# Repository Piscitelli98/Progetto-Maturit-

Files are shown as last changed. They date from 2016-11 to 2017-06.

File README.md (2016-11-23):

# Progetto Maturità
Cassaforte
Titolo: Cassaforte con Arduino.
Gruppo: Perego Daniele, Piscitelli Federico, Leggio Giuseppe.
Spiegazione: Un modello di cassaforte costruita con Arduino, integrando un sensore di impronte digitali, un tastierino numerico, un display e una shield per la comunicazione wireles.
La cassaforte permetterà di avere accesso a un database in cui sono registrati tutti gli accessi.
Saremo in grado di rilevare anche la persona che ha eseguito l'accesso poichè si avranno a disposizione degli identificativi grazie all'impronta digitale.
L'accesso a questo database sarà effettuato tramite applicazione android.

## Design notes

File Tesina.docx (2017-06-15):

# Cassaforte 2.0

Di

Piscitelli Federico

Leggio Giuseppe

Perego Daniele

Rosselli Mattia

# Introduzione

L’ idea

L’ idea di creare una cassaforte smart è nata dall’ esigenza di creare un prodotto innovativo non ancora presente sul mercato. Un altro aspetto che ci ha spinto alla realizzazione di questo progetto è la possibilità di estendere il meccanismo di sicurezza ad altri ambiti, come ad esempio in quello della domotica.

Quali funzioni offre

Oltre ad essere una normale cassaforte, il nostro prototipo offre diverse funzionalità che rappresentano sicuramente delle innovazioni nel campo della sicurezza. Prime fra tutte:

- Sensore di impronte digitali
- Applicazione android
- Comunicazione bluetooth
- Registrazione con successiva consultazione tramite app

# Obiettivi

La Cassaforte 2.0 si pone come obiettivo quello di creare un progetto sicuro, affidabile e intuitivo, con l’aggiunta di alcune funzioni “smart”.

INNOVAZIONE

Questo progetto pone come primo obiettivo quello di trasformare un oggetto millenario in qualcosa di moderno, al passo con i tempi.

Il primo passo per la modernizzazione della cassaforte avviene tramite l’aggiunta di un sensore per il rilevamento dell’impronta digitale, diventato ormai un must della sicurezza.

Per rendere ancora più all’avanguardia questo progetto ci si è chiesto: “Quale oggetto oggi rappresenta l’innovazione?” Subito è saltato all’occhio lo smartphone che al giorno d’ oggi è parte integrante della nostra vita.

Il modo migliore per combinare questi due mondi è stato quello di sviluppare un’applicazione dedicata alla gestione della cassaforte.

Nonostante il progetto preveda l’utilizzo dello smartphone per alcune funzioni, la cassaforte può svolgere la sua normale funzione di custodia anche senza l’obbligo di utilizzo dell’applicazione, rendendo accessibile a tutti , grandi e piccoli, le sue funzioni, ampliando così il range di persone raggiungibili nel mercato.

SICUREZZA

Uno degli obiettivi fondamentali della Cassaforte 2.0 è quello di garantire una sicurezza costante ed efficiente. Per fare ciò il prototipo propone due livelli di sicurezza:

1. Tastierino numerico
2. Sensore d’ impronte digitali

Proprio grazie a questo doppio livello di sicurezza, anche scoperto il codice di apertura, risulta impossibile l’apertura in maniera fraudolenta della cassaforte.

# Strumenti

La Cassaforte 2.0 utilizza un Arduino che permette una completa adattabilità data dalla possibilità di poter compilare il codice in base alle necessità del cliente, dando la possibilità di aggiungere o modificare la varia componentistica.

STRUMENTI UTILIZZATI

- Arduino mega (modello) e componentistica reperibile in rete. Si è optato per il mega data la sua migliore capacità di calcolo e la possibilità di inserimento di più pin.

- Cassaforte in legno per simulare un reale caso d’uso.

- Android studio e Arduino come ambienti di sviluppo per la programmazione.

- Librerie reperibili in internet ed adattate al caso d’uso specifico per permettere la comunicazione e la realizzazione di servizi mirati.

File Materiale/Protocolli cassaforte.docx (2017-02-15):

# Protocolli cassaforte

# Registrazione del primo utente

Client

Android

Server

Arduino

connessione

ok

registra;”user”;”psw”;”cod”

ok

Close

# Login

Client

Android

Server

Arduino

connessione

ok

Log;”user”;”psw”

ok

Close

# Apertura cassaforte da applicazione

close

ok

apri;”cod”;”user”

ok

connessione

Client

Android

Server

Arduino

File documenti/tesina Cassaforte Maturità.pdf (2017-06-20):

## 5ªA Informatica e Telecomunicazioni Esame di Stato A.S. 2016/2017

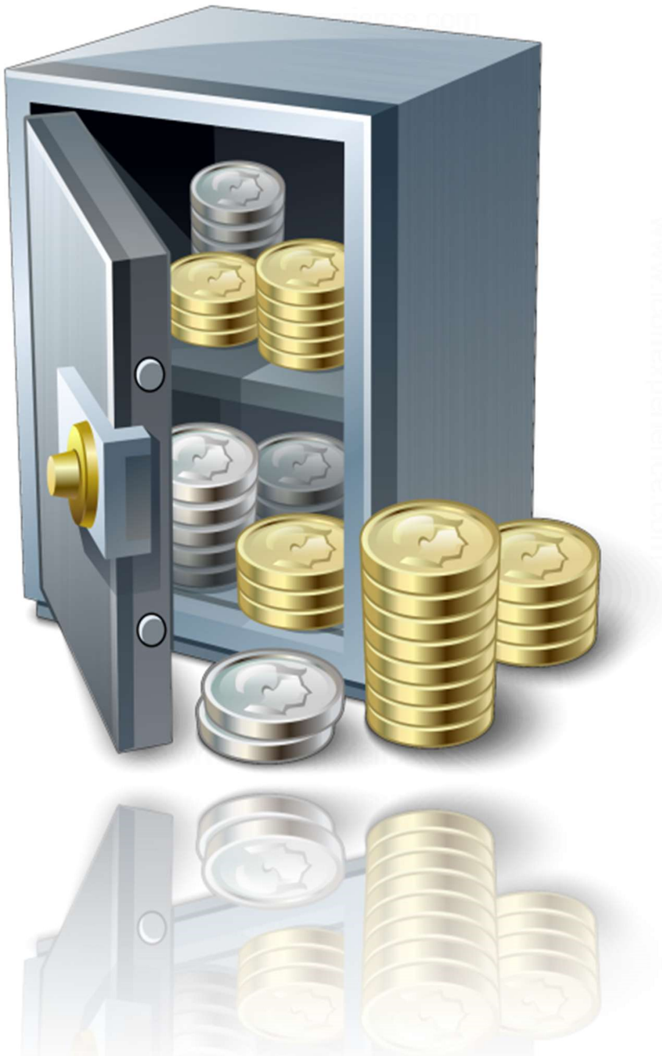
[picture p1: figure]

# Cassaforte

2.0

Di

Piscitelli Federico
Leggio Giuseppe
Perego Daniele
Rosselli Mattia

1

SOMMARIO

2

INTRODUZIONE

L’ IDEA
L’ idea di creare una cassaforte smart è nata dall’ esigenza di creare un prodotto innovativo non ancora presente sul mercato. Un altro aspetto che ci ha spinto alla realizzazione di questo progetto è la possibilità di estendere il meccanismo di sicurezza ad altri ambiti, come ad esempio in quello della domotica.

QUALI FUNZIONI OFFRE
Oltre ad essere una normale cassaforte, il nostro prototipo offre diverse funzionalità che rappresentano sicuramente un approccio innovativo nel campo della sicurezza. Prime fra tutte:
- Applicazione Android
- Comunicazione Bluetooth
- Registrazione con successiva consultazione tramite app
- Sensore di riconoscimento biometrico

3

OBIETTIVI

La Cassaforte 2.0 si pone come obiettivo quello di creare un progetto sicuro, affidabile e intuitivo, con l’aggiunta di alcune funzioni “smart”.

INNOVAZIONE
Questo progetto pone come primo obiettivo quello di trasformare un oggetto millenario in qualcosa di moderno, al passo con i tempi.
Il primo passo per la modernizzazione della cassaforte avviene tramite l’aggiunta di un sensore per il rilevamento dell’impronta digitale, diventato ormai un must della sicurezza.
Per rendere ancora più all’avanguardia questo progetto ci si è chiesto: “Quale oggetto oggi rappresenta l’innovazione?”
Subito è saltato all’occhio lo smartphone che al giorno d’ oggi è parte integrante della nostra vita.
Il modo migliore per combinare questi due mondi è stato quello di sviluppare un’applicazione dedicata alla gestione della cassaforte. Nonostante il progetto preveda l’utilizzo dello smartphone per alcune funzioni, la cassaforte può svolgere la sua normale funzione di custodia anche senza l’obbligo di utilizzo dell’applicazione, rendendo accessibile a tutti , grandi e piccoli, le sue funzioni, ampliando così il range di persone raggiungibili nel mercato.

SICUREZZA

Uno degli obiettivi fondamentali della Cassaforte 2.0 è quello di garantire una sicurezza costante ed efficiente.
Per fare ciò il prototipo propone una doppia chiave in base al caso d’uso:

### 1. Tastierino numerico 2. Sensore d’ impronte digitali

Proprio grazie a questo doppio livello di sicurezza, anche scoperto il codice di accesso, risulato quasi impossibile l’apertura in maniera fraudolenta della cassaforte.

4

STRUMENTI

La Cassaforte 2.0 utilizza un Arduino che permette una completa adattabilità, data dalla possibilità di poter compilare il codice in base alle necessità del cliente, dando la possibilità di aggiungere o modificare la varia componentistica.

STRUMENTI UTILIZZATI

- Arduino Mega
- Modulo RTC (Real Time Clock, utile per tenere ora e giorno)
- Modulo Bluetooth HC-06
- Modulo per l’espansione della memoria
- Sensore d’impronte digitale
- Schermo LCD
- Motorino Step to Step
- Cassaforte in legno per simulare un reale caso d’uso.
- Android Studio e Arduino IDE come ambienti di sviluppo per la programmazione.
- Librerie fornite dai vari costruttori dei componenti

Durante la fase di progettazione si è deciso di utilizzare un Arduino Mega, a dispetto di un Arduino UNO, per la posssibilità di scalabilità che offriva il primo, data la quantità di pin disponibili.

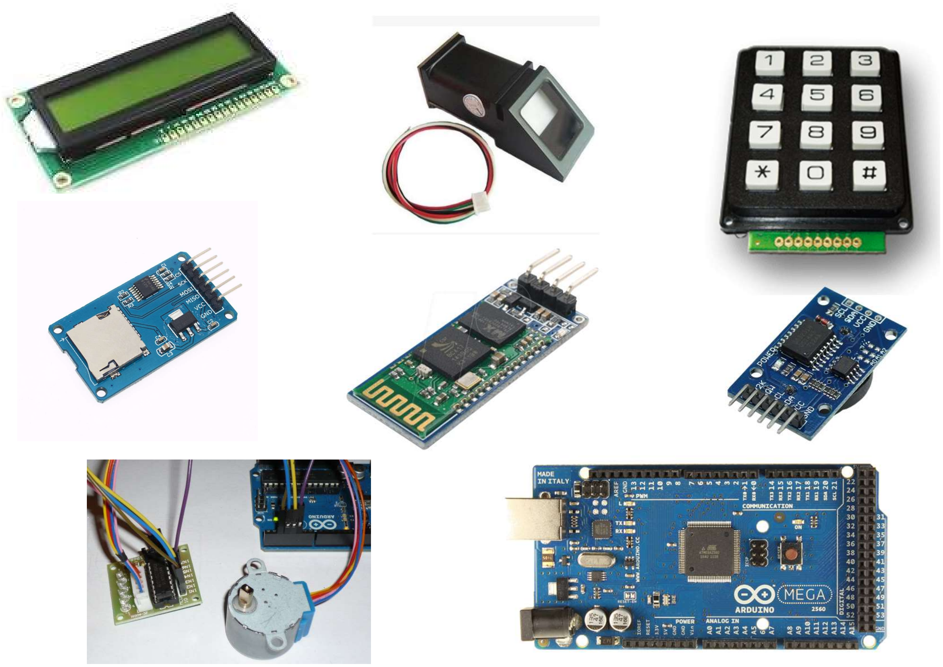
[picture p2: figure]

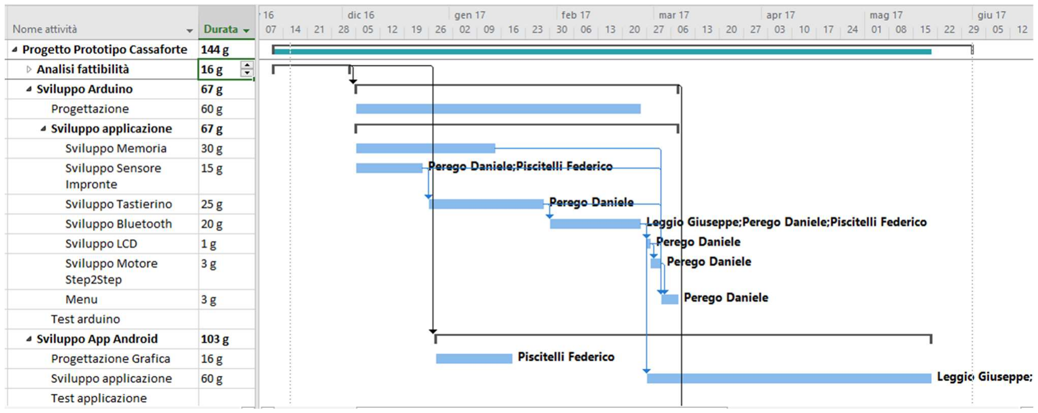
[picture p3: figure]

5

METODOLOGIA E SVILUPPO
Essendoci due ambienti di sviluppo differenti si è optato per la divisione del team in due rami.

Il primo gruppo, composto da Leggio e Piscitelli, si è impegnato nella programmazione e nello sviluppo dell’applicazione Android.
Il secondo gruppo, composto da Perego e Rosselli, ha avuto come incarico il montaggio dei vari componenti hardware e la programmazione delle sue funzionalità.

TEMPISTICHE
Per organizzare al meglio i tempi e le risorse abbiamo utillizzato Microsoft Project, con il qule siamo riusciti a stilare una WBS che è stata rispettata da tutti i componenti del gruppo.

6

ANDROID
Lo sviluppo dell’applicazione Android si è divisa in tre fasi:
- Progettazione e realizzazione della grafica;
- Gestione file di log e ultimi accessi scaricati;
- Implementazione della comunicazione Bluetooth per le varie funzionalità.
Durante la prima fase, si è realizzato un “bozzetto” in Android Studio di come sarebbe dovuta essere l’applicazione. Si è passati poi alla creazione dei colori per i bottoni e per lo sfondo. Successivamente sono state implementate tutte le animazioni nelle varie activity.
La parte più impegnativa a livello di design è arrivata quando si è dovuto implementare il Fragment, un elemento introdotto con Android 3, per la creazione di interfacce grafiche. È una sorta di sub activity. Infatti il suo funzionamento è legato ad un’activity principale.
La struttura di questo tipo di programmazione consiste nel creare diversi layout per ogni fragment (vista) che viene implementata, essi poi vanno collegati a una corrispondete classe, proprio come se fosse un’activity, con la differenza che poi queste diverse “viste” sono gestite da un’activity principale.
Questo ne rende più difficile la gestione in quanto tutti i metodi per richiamare dei componenti grafici dal file xml sono differenti. Ad esempio per richiamare un bottone in un’activity semplice si scrive questa linea di codice:

Button button = (Button)findViewById(R.id.button0);
Mentre in un Fragment:
View rootView = inflater.inflate(R.layout.fragment_layout, container, false);
Button button =
(Button)rootView.findViewById(R.id.button0);

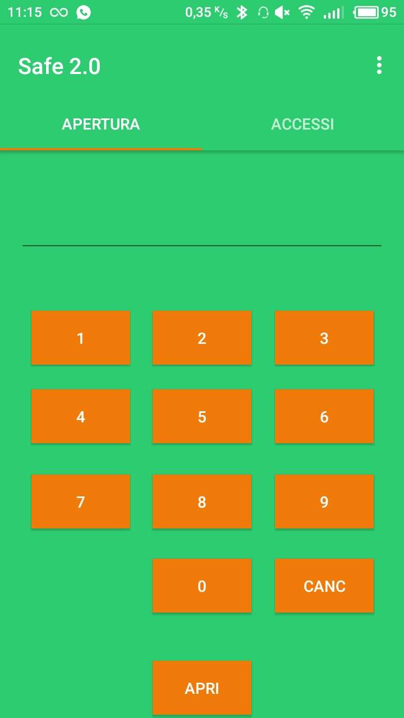
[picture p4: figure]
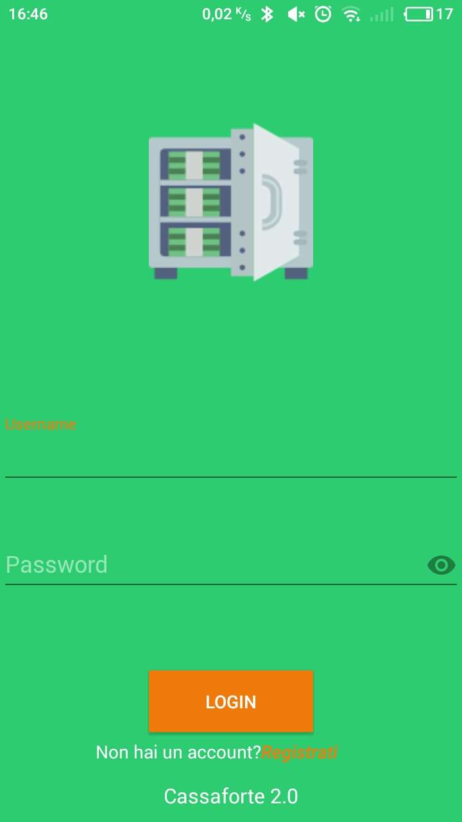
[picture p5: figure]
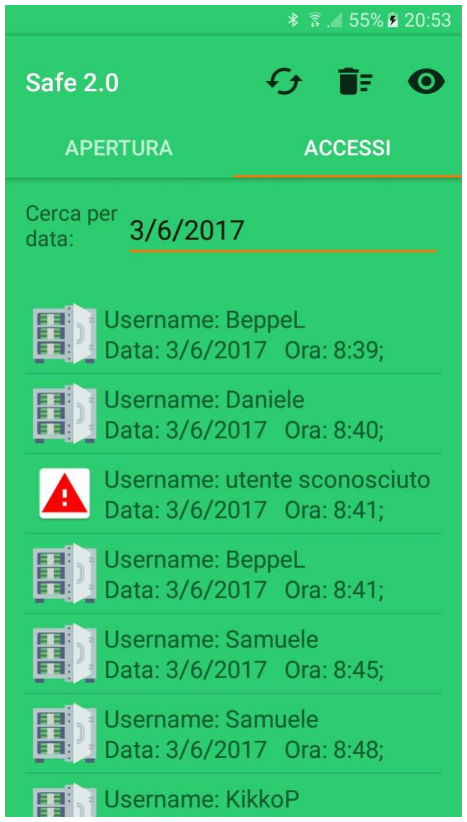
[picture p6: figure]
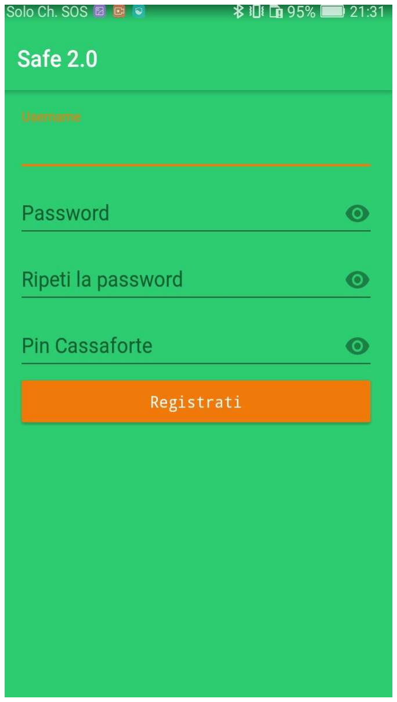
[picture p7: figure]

7

La fase seguente è stata l’implementazione della gestione dei file. L’implementazione si è resa necessaria perché si voleva garantire la possibilità di utilizzare l’applicazione in parte anche quando l’applicazione non è connessa alla Cassaforte.
I file di log che vengono registrati sono due:
- Il primo che memorizza i dati di accesso una volta che è stato eseguito con successo il login tramite connessione.
- Il secondo che memorizza gli ultimi accessi scaricati.

private Boolean leggiFileLog(String datiLogin)
String line = "";//Riga letta BufferedReader br;
boolean trovato = false;
try {
FileInputStream fin = openFileInput(filename);
int c;//Indice linea del file corrente
while ((c = fin.read()) != -1) {//legge un carattere alla volta if ((char) c != '%') //carattere che delimita login salvata line += Character.toString((char) c);//forma login
else {//una volta trovato lo confronta con i
if (line.equals(datiLogin)) {//dati inseriti dall’utente trovato = true;
break;
}
line = "";
}
}
} catch (Exception e) {}
return trovato;//ritorna true o false in base se ha trovato o meno la corrispondenza con i dati inseriti dall'utente
}

L’ultima fase, quella più lunga e in cui sono emerse notevoli difficoltà, è stata quella in cui è stata implementata la comunicazione Bluetooth. Per comunicare con la Cassaforte utilizza tre elementi:
- La classe “BluetoothComIno”, creata da Leggio. Il principio di questa classe è quello di istanziare una socket, che ha come IP il MAC del modulo HC-06, e come porta richiama questo metodo,
BluetoothDevice.createRfcommSocketToServiceRecord(uuid), il quale permette di aprire una connessione p2p.
- Un thread per la ricezione dei dati. Esso viene utilizzato poiché, oltre a un motivo di strettamente computazionale, nel sistema Android, questo tipo di operazioni non possono essere gestite dal main-thread, bisogna utilizzare dei worker-thread.
- Un handler. Poiché i dati devono poi essere elaborati dal main thread, diventa necessario l’utilizzo di questo oggetto, perché permette la comunicazione tra main-thread e worker-thread.
In sintesi quindi, questo strumento fa da intermediario tra worker thread e main thread utilizzando un oggetto di tipo Message, il

8

quale viene aggiornato dal worker thread e passato tramite bundle al main thread in cui poi viene elaborato.

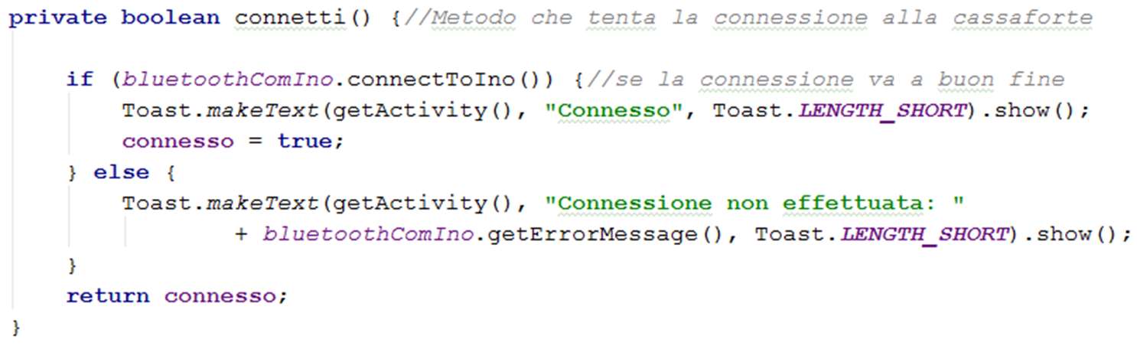
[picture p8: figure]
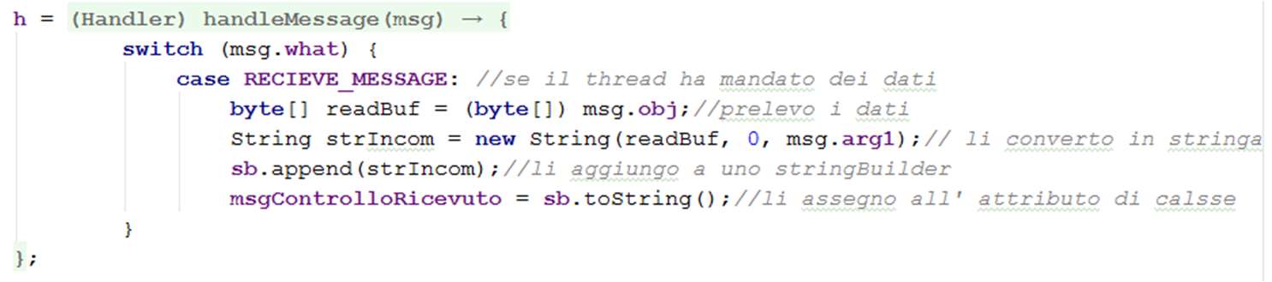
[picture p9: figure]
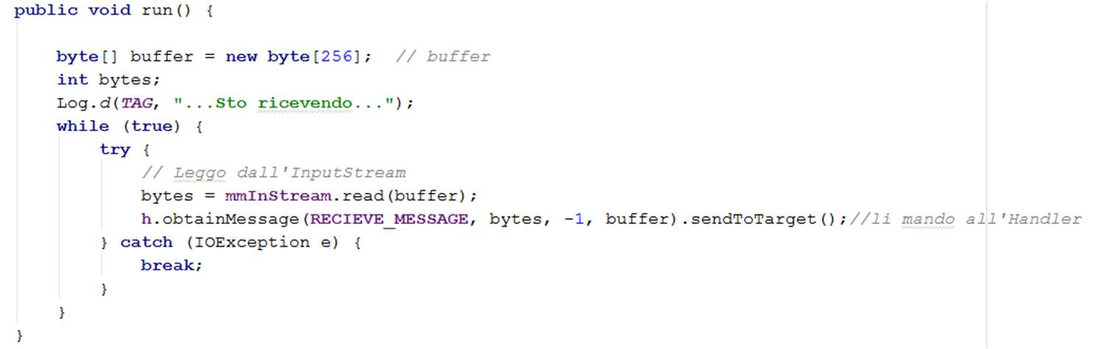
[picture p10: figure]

Durante la programmazione della comunicazione Bluetooth sono stati riscontrati diversi problemi, soprattutto riguardanti la ricezione. Molte volte infatti venivano persi o duplicati caratteri.
Il problema derivava principalmente da due fattori:
- l’Arduino venivano utilizzato spesso in modalità “Debug” e ciò creava degli scompensi nella comunicazione.
- Un’alimentazione non sufficiente. Questo è stato riscontrato nei casi in cui è stato usato un net-book come alimentatore, dal quale esce corrente in modo poco stabile. Se l’Arduino è collegato invece ad una fonte di alimentazione esterna, che non sia una porta USB del pc, questo problema non persiste.
Altri problemi sono emersi nuovamente per via dell’utilizzo del via del menu Fragment, per via del suo ciclo di vita differente rispetto alla normale activity.
Essendo collegati entrambi alla stessa activity, essi vengono creati allo

9

stesso momento. Di conseguenza è stato necessario anche sincronizzare quale dei due si doveva connettere per primo, e le varie fasi di disconnessione e riconnessione.

ARDUINO
Anche lo sviluppo di Arduino e dei componenti è stato diviso in due momenti:
- Programmazione e test dei singoli componenti
- Assemblaggio e test complessivo
Per la parte fisica abbiamo subito riscontrato delle problematiche, siccome abbiamo dovuto attendere più di un mese dall’acquisto dei componenti affinché questi arrivassero. Una volta arrivata la componentistica, il team hardware si è diviso in due e ha cominciato a testare e a programmare uno ad uno ogni modulo.
I primi problemi sono stati riscontrati con il tastierino numerico che non corrispondeva allo schema elettrico fornitoci dal venditore. Quindi il gruppo hardware si è dovuto occupare della stesura dello schema elettrico corretto, aprendo il tastierino per controllarne il reale funzionamento dei pin.
Arrivati al test del sensore d’impronte digitali abbiamo avuto altri problemi, dato che la libreria fornitaci dal costruttore non era in grado di rilevare il sensore. Per ovviare a questo inconveniente abbiamo dovuto ricercare una libreria che si adattasse al nostro sensore. Fortunatamente abbiamo trovato la libreria “AdaFruit-Fingerprint” che pur non essendo quella apposita per il modello del sensore, funzionava perfettamente. Dopo aver testato e programmato ogni componente singolarmente il team preposto per lo sviluppo di Arduino ha montato su una breadboard tutti i componenti e ha cominciato lo sviluppo del “Menu”, ossia il programma che gestisce le funzionalità della cassaforte sincronizzando il lavoro di tutti i componenti.

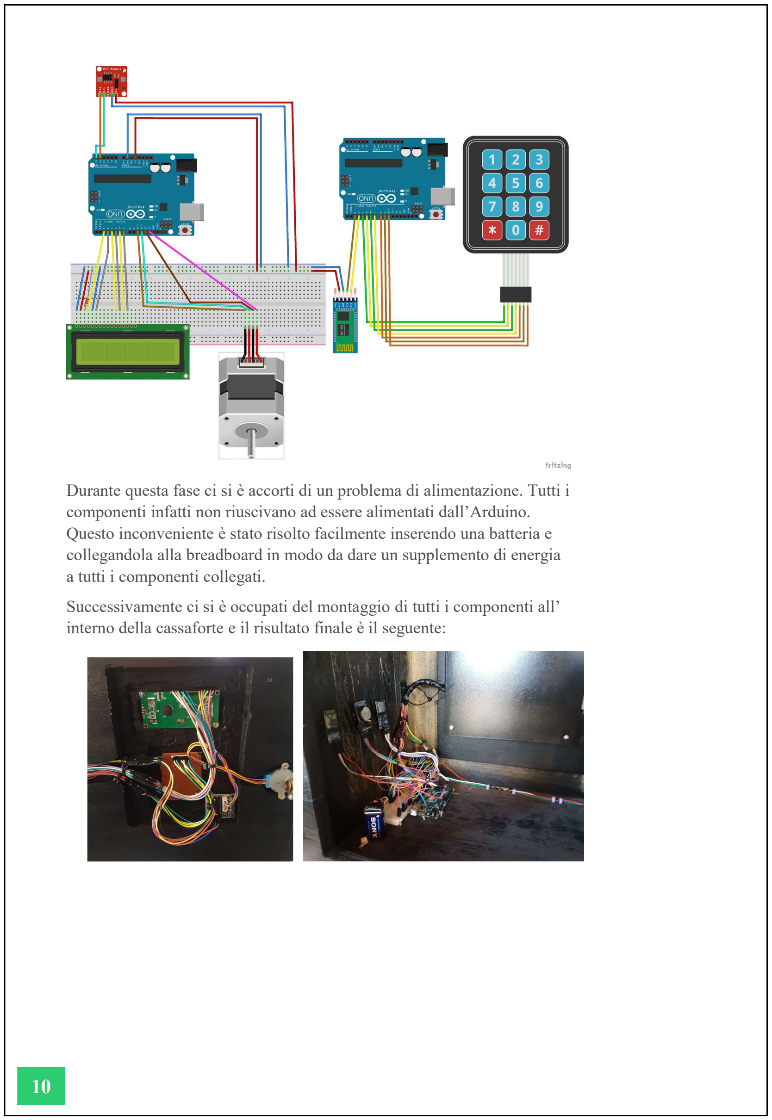
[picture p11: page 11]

10

Durante questa fase ci si è accorti di un problema di alimentazione. Tutti i componenti infatti non riuscivano ad essere alimentati dall’Arduino. Questo inconveniente è stato risolto facilmente inserendo una batteria e collegandola alla breadboard in modo da dare un supplemento di energia a tutti i componenti collegati.
Successivamente ci si è occupati del montaggio di tutti i componenti all’ interno della cassaforte e il risultato finale è il seguente:

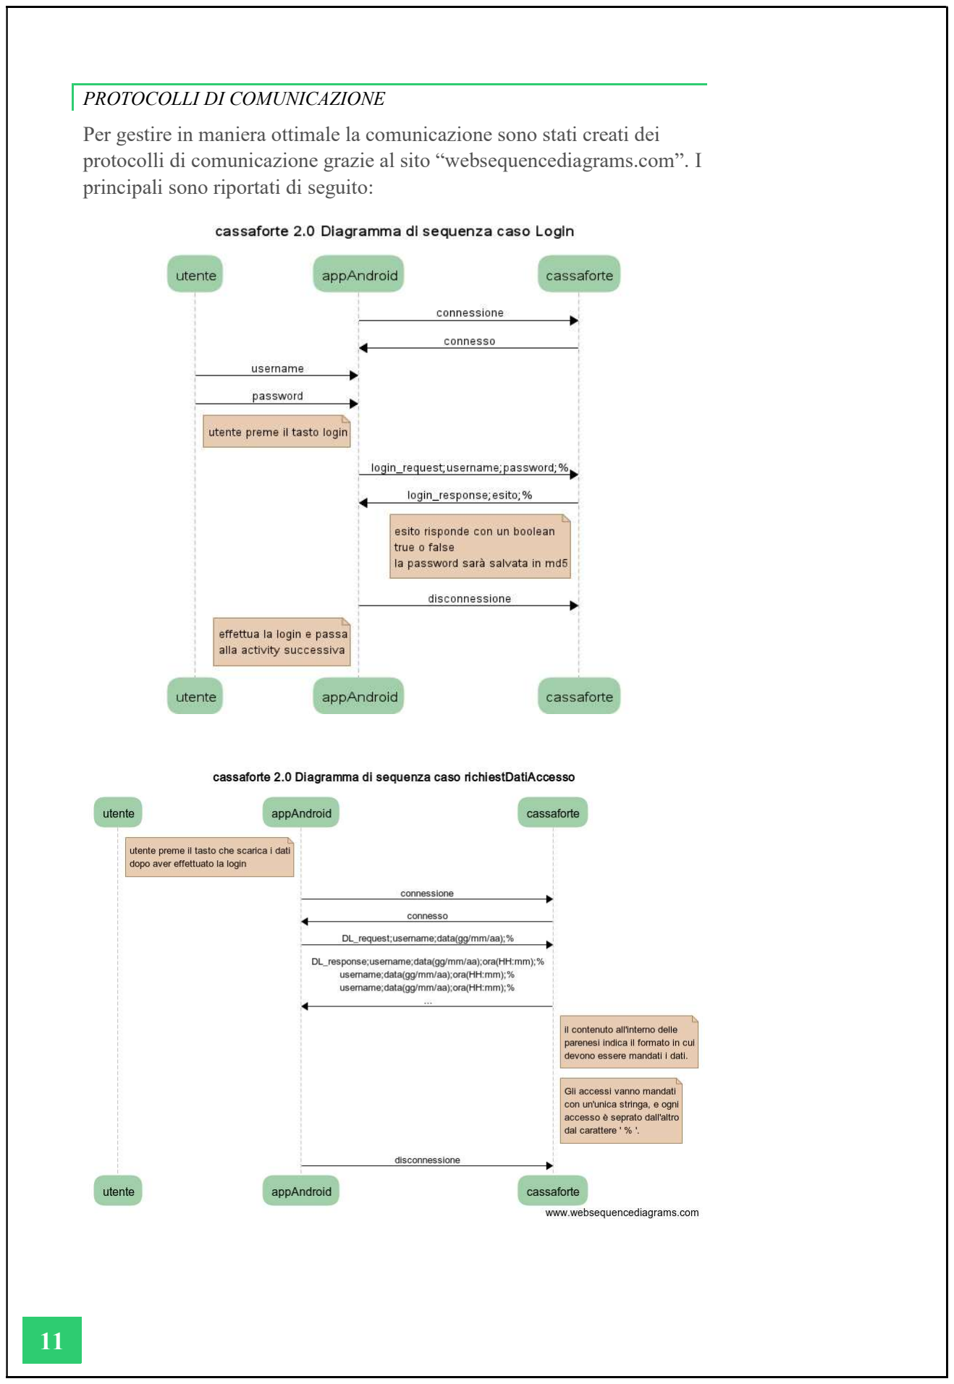
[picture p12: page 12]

11

PROTOCOLLI DI COMUNICAZIONE
Per gestire in maniera ottimale la comunicazione sono stati creati dei protocolli di comunicazione grazie al sito “websequencediagrams.com”. I principali sono riportati di seguito:

12

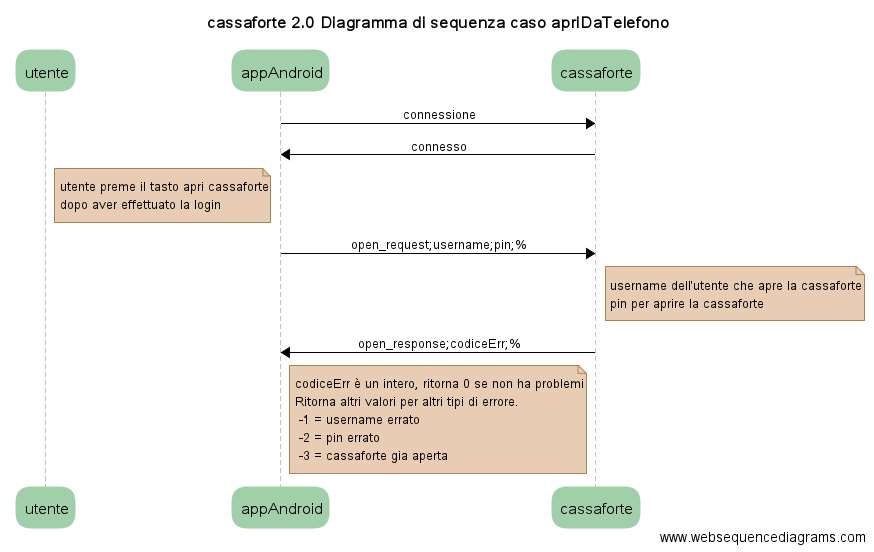
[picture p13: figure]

13

BETA TEST

Durante il beta test, il gruppo si è riunito e ha provato ogni funzionalità della Cassaforte 2.0, risolvendo eventuali errori nella comunicazione e aumentando le prestazioni in termini di velocità.
Principalmente sono stati corretti:
- Ritardi nella comunicazione
- Errori nella comunicazione
- Bug dell’applicazione
- Errori nella registrazione degli utenti su Arduino
- Errori nell’invio degli accessi in base alla data

POSSIBILI MIGLIORIE

Durante la fase del beta test, il team ha anche pensato a dei
possibili miglioramenti che potrebbero rendere ancora più
efficiente il progetto:
- Aggiungere una fotocamera per scattare delle foto a chi effettua gli accessi
- Usare Raspberry al posto di Arduino Mega per gestire al meglio le richieste dell’utente e per potersi connettere alla rete e salvare gli accessi su un database, contattabile anche da applicazione tramite un web service.
- Utilizzare un modulo wifi al posto del modulo Bluetooth per velocizzare la comunicazione e per renderla più stabile.

14

FUNZIONAMENTO

PRIMO AVVIO SENZA APPLICAZIONE
Se si vuole utilizzare la cassaforte senza applicazione al primo avvio bisognerà salvare l’impronta digitale dell’utente digitando il codice *5 e premendo successivamente # per inviare. Verrà richiesto il pin della cassaforte (fornito dagli sviluppatori) e successivamente partirà la sequenza per salvare l’impronta. Il sensore d’impronte (in basso a sinistrà) comincerà a lampeggiare. Bisognerà appoggiare il dito e tenerlo fermo per 5 secondi. La luce smetterà di lampeggiare. Ripetere la sequenza fino a quando sullo schermo non comparirà la scritta “Impronta registrata”.
La cassaforte è pronta ora per l’ utilizzo.
Ogni qualvolta che si vorrà accedere alla cassaforte bisognerà digitare il pin e premere #, inserire l’impronta appena il sensore comincerà a lampeggiare e attendere l’apertura della Cassaforte. Una volta finito l’ utilizzo, si dovrà chiudere manualmente lo sportello e si dovrà premere # per avviare la chiusura della cassaforte.

PRIMO AVVIO CON APPLICAZIONE
Se si vuole utilizzare la cassaforte con l’applicazione bisognerà, come prima cosa, creare un nuovo utente. Quindi una volta aperta l’applicazione l’utente dovrà andare nell’apposita activity e inserire uno username (minimo 6 caratteri), una password (minimo 5 caratteri) e il pin della cassaforte. Inviando tutto alla cassaforte verrà richiesto di salvare l’impronta dell’utente. Il sensore comincerà a lampeggiare e la procedura da seguire è la medesima descritta sopra. Una volta che l’utente ha l’account registrato, può usufruire dei servizi dell’applicazione effettuando la login. Ad esempio potrà aprire la cassaforte da telefono o potrà controllare gli accessi che sono stati effettuati in un determinato giorno.

15

RINGRAZIAMENTI

Il progetto ci ha portato via molto tempo negli ultimi mesi e nonostante i nostri sforzi continui ci sono persone esterne al nostro gruppo che ci hanno sostenuto ed aiutato nella realizzazione di questo prototipo.
In particolare vogliamo ringraziare Perego Attilio per il tempo dedicatoci per la realizzazione della cassaforte in legno e i prof per la disponibilità nel fornire consigli e aiuti quando necessario.

BIBLIOGRAFIA E SITOGRAFIA

www.stackoverflow.com
www.arduino.com
www.github.com
developer.android.com
www.androidworld.it

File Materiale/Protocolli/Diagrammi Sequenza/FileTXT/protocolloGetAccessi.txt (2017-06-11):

title cassaforte 2.0 Diagramma di sequenza caso richiestDatiAccesso

participant utente
participant appAndroid
participant cassaforte

note right of utente: utente preme il tasto che scarica i dati \ndopo aver effettuato la login
appAndroid->cassaforte: connessione
cassaforte->appAndroid: connesso
appAndroid->cassaforte: DL_request;username;data(gg/mm/aa);%
cassaforte->appAndroid: DL_response;username;data(gg/mm/aa);ora(HH:mm);% \nusername;data(gg/mm/aa);ora(HH:mm);% \nusername;data(gg/mm/aa);ora(HH:mm);% \n...
note right of cassaforte: il contenuto all'interno delle \nparenesi indica il formato in cui \ndevono essere mandati i dati.
note right of cassaforte:Gli accessi vanno mandati \ncon un'unica stringa, e ogni \naccesso è seprato dall'altro \ndal carattere ' % '.
appAndroid->cassaforte: disconnessione

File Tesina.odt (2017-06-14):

Cassaforte 2.0

Di

Piscitelli Federico

Leggio Giuseppe

Perego Daniele

Rosselli Mattia

Sommario

# Introduzione

L’ idea

L’ idea di creare una cassaforte smart è nata dall’ esigenza di creare un prodotto innovativo non ancora presente sul mercato. Un altro aspetto che ci ha spinto alla realizzazione di questo progetto è la possibilità di estendere il meccanismo di sicurezza ad altri ambiti, come ad esempio in quello della domotica.

Quali funzioni offre

Oltre ad essere una normale cassaforte, il nostro prototipo offre diverse funzionalità che rappresentano sicuramente delle innovazioni nel campo della sicurezza. Prime fra tutte:

- Sensore di impronte digitali
- Applicazione android
- Comunicazione bluetooth
- Registrazione accessi con possibilità di consultazione tramite app

# Obiettivi

La Cassaforte 2.0 si pone come obiettivo quello di creare un progetto sicuro, affidabile e intuitivo, con l’aggiunta di alcune funzioni “smart”.

innovazione

Questo progetto pone come primo obiettivo quello di trasformare un oggetto

millenario in qualcosa di moderno, a passo con i tempi.

Il promo passo per la modernizzazione della cassa forte avviene tramite

l’aggiunta di un sensore di rilevamento di impronta digitale, ormai un must

per la gestione della sicurezza.

Per rendere ancora più all’avanguardia questo progetto ci si è chiesto:

Quale oggetto oggi rappresenta l’innovazione?

E subito è saltato all’occhio lo Smartphone.

Il modo migliore per combinare questi due mondi è stato quello di creare un

applicazione dedicata, atta alla gestione della cassaforte stessa.

Nonostante lo Smarphone sia alla portata di tutti, la cassaforte svolge la sua

normale funzione di custodia anche senza l’obbligo di utilizzo di quest’ultima,

rendendo l’utilizzo possibile a tutti, grandi e piccoli, ampliando così il

range di persone raggiungibili nel mercato.

Sicurezza

Uno degli obiettivi fondamentali della cassaforte 2.0 è quello di garantire una sicurezza costante ed efficiente.

Per fare ciò il prototipo propone due livelli di sicurezza:
1) Tastierino numerico,

2) Rilevatore di impronta.

Proprio grazie a questo doppio livello di sicurezza, anche scoperto il codice di

apertura, risulta pressochè impossibile l’apertura in maniera fraudolenta della

cassaforte.

# strumenti

La cassaforte 2.0 utilizza la tecnologia Arduino che permette una completa adattabilià data dalla possibilità di poter compilare il codice in base alle necessità del cliente, dando la possibilità di aggiungere o modificare la varia componentistica.

Strumenti utilizzati

- Arduino mega (modello) e componentistica reperibile in rete. Si è optato per il mega data la sua migliore capacità di calcolo e la possibilità di inserimento di più pin.

- Cassaforte in legno per simulare un reale caso d’uso.

- Android studio e Arduino come ambienti di sviluppo per la programmazione.

- Librerie reperibili in internet ed adattate al caso d’uso specifico per permettere la comunicazione e la realizzazione di servizi mirati.

Metodologia e sviluppo

Essendoci due ambienti di sviluppo differenti si è optato per la divisione del

team in due rami.

Il primo gruppo, composta da Leggio e Piscitelli si è impegnato nello programmazione e nello sviluppo dell’applicazione android.

Il secondo gruppo, composta a sua volta da Perego e Rosselli ha avuto come

incarico quello collegare i vari hardware ad Arduino e in un secondo momento

di programmarne le funzionalità.

Android studio

Da definire

arduino

da definire

comunicazione

da definire

beta test

funzionamento

ringraziamenti

Il progetto ci ha portato via molto tempo negli ultimi mesi, e nonostante i nostri sforzi continui ci sono persone esterne al nostro gruppo che ci hanno sostenuto ed aiutato nella realizzazione di questo prototipo.
In primo luogo vogliamo ringraziare Perego Attilio per il tempo dedicatoci per la realizzazione della cassaforte in legno.
Vogliamo anche ringraziare il professore Giuseppe Comparin e Luca De Simone per l’impegno e l’attenzione nel seguire passo dopo passo il nostro progetto, partendo da una semplice idea fino alla realizzazione del prototipo completo.
Ringraziamo anche Giovanni Breviario e Matteo Longhi per essere sempre stati disponibili ed esaurienti nelle domande a loro poste inerenti a parti del progetto.
Ringraziamo anche le nostre famiglie per averci sostenuto e supportato in tutto il nostro percorso scolastico.

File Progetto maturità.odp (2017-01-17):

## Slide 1

Cassaforte Elettronica

Progetto di maturità 2016/17

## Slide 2

Obbiettivo:

L’obbiettivo di questo progetto è quello di riprodurre una cassaforte sicura e facile da gestire, alla portata di tutti i possibili utenti.

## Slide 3

Realizzazione:

Il progetto si svilupperà su 3 piano diversi:

1. L’assemblaggio dei vari componenti e la loro programmazione per garantirne la sicurezza.
2. La creazione di un Database contente tutte le informazioni riguardanti gli accessi
3. Lo sviluppo di un Applicazione per Smartphone atta a gestire la cassaforte

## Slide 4

Sicurezza:

Per garantire la sicurezza sfrutteremo Arduino e diverse sue componenti:

- Tastierino: Verrà memorizzata la sequenza corretta di numeri da digitare per poter sbloccare la cassaforte.
- Sensore di impronta digitale: A codice corretto sarà richiesta un impronta digitale per poter sbloccare la cassaforte.
- Fotocamera: Scatterà una foto ogni qualvolta venga inserito un codice sbagliato o l'improta digitale non sia corrispondente al profilo.

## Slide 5

Database:

Si installerà su Arduino un espansione della memoria per garantire il salvataggio di alcune informazioni importanti:

- Ora del tentativo di accesso(grazie ad un clock).
- Codice inserito.
- Fotografia.

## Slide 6

Applicazione:

Verrà sviluppata un app mobile che permetterà la facile gestione della cassaforte e della sua sicurezza tramite diverse funzioni:

- Possibilità di sblocco direttamente da applicazione.
- Possibilità di accedere direttamente al Database.
- Possibilità di aggiungere account per accedere alla cassaforte.

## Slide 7

Foto:

Foto:

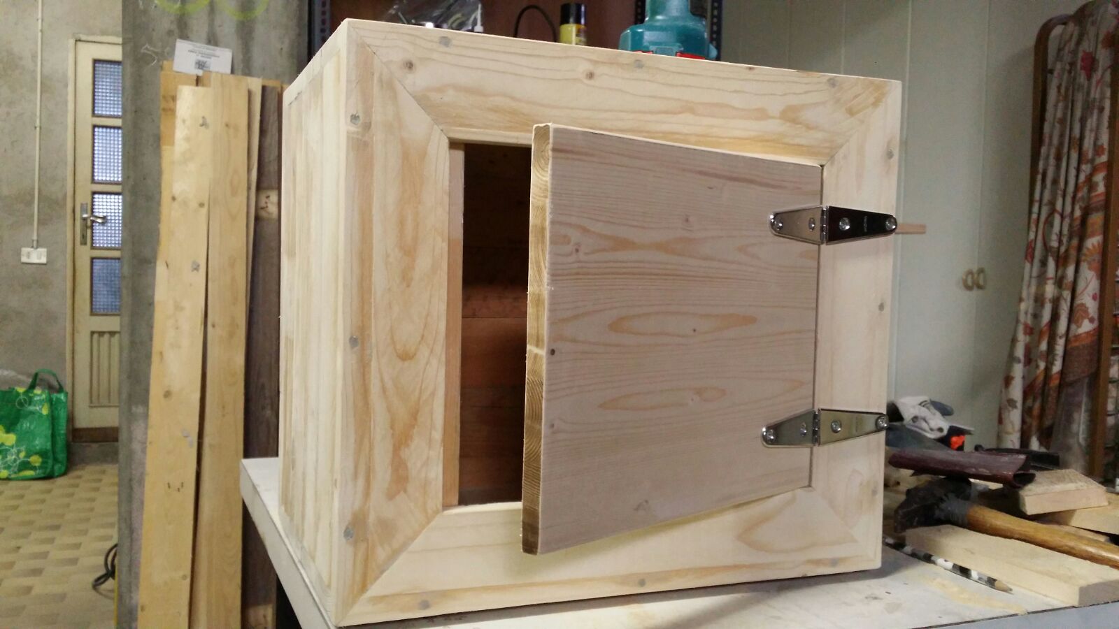
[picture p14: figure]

Struttura della cassaforte.

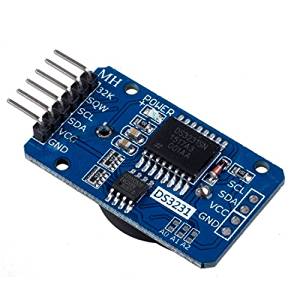
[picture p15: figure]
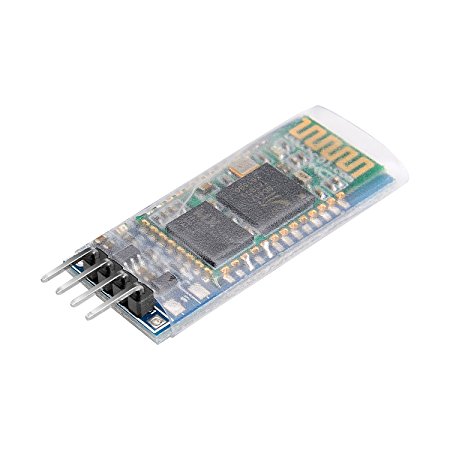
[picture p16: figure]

Componente per creare una rete bluetooth.

Clock per calcolare il tempo.

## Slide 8

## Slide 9

Partecipanti:

- Rosselli Mattia

- Leggio Giuseppe

-Piscitelli Federico

-Perego Daniele

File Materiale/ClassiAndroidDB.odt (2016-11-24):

Classe SQLiteClosable: https://developer.android.com/reference/android/database/sqlite/SQLiteClosable.html Da rivedere, forse inutile.

Collegare il database metodi: https://developer.android.com/reference/android/database/sqlite/SQLiteOpenHelper.html

Class: SQLiteDatabase (https://developer.android.com/reference/android/database/sqlite/SQLiteDatabase.html)

Method: getReadableDataBase: Crea e/o apre il DB. È consigliabile chiamre questo comando con un thread perchè potrebbe richiedere molto tempo.

Return: oggetto di classe SQLiteDatabase (https://developer.android.com/reference/android/database/sqlite/SQLiteDatabase.html).

Exception: Solleva eccezioni di tipo SQLiteException (https://developer.android.com/reference/android/database/sqlite/SQLiteException.html), se il Db non può essere aperto.

Operare sul database: https://developer.android.com/reference/android/database/sqlite/SQLiteDatabase.html

Circa a metà pagina metodo "query" (Ctrl+f "query").

Esempio di come operare:

- http://stackoverflow.com/questions/12298835/how-to-retrieve-data-from-sqlite-database-in-android-and-display-it-in-textview

- http://www.html.it/pag/49180/database-e-sqlite/ Con spiegazione

Per lavorare su un oggetto SQLiteDatabase, la prima cosa da fare è recuperarne un riferimento. Lo si può fare con i metodi di SQLiteOpenHelper, getReadableDatabase() e getWriteableDatabase() che restituiscono, rispettivamente, un riferimento al database “in sola lettura” e uno che ne permette la modifica.

Sull’oggetto SQliteDatabase recuperato, si svolge una delle quattro operazioni CRUD, e azioni fondamentali della persistenza (Create, Read, Update, Delete).
Nelle API Android per Sqlite esiste almeno un metodo per ogni tipo di azione:
- query: esegue la lettura sulle tabelle: mette in pratica il SELECT sui dati. I suoi svariati overload predispongono argomenti per ogni parametro che può essere inserito in una interrogazione di questo tipo (selezione, ordinamento, numero massimo di record, raggruppamento, etc.);

Per utilizzare il codice SQL in modo esplicito si possono usare i metodi della classe SqliteDatabase: execSQL e rawQuery.

Class Cursor: Serve per elaborare i risultati ottenuti dalle interrogazioni del database.
Methods: moveToNext, moveToFirst, moveToLast, getString, getLong, getColumnIndex ecc.

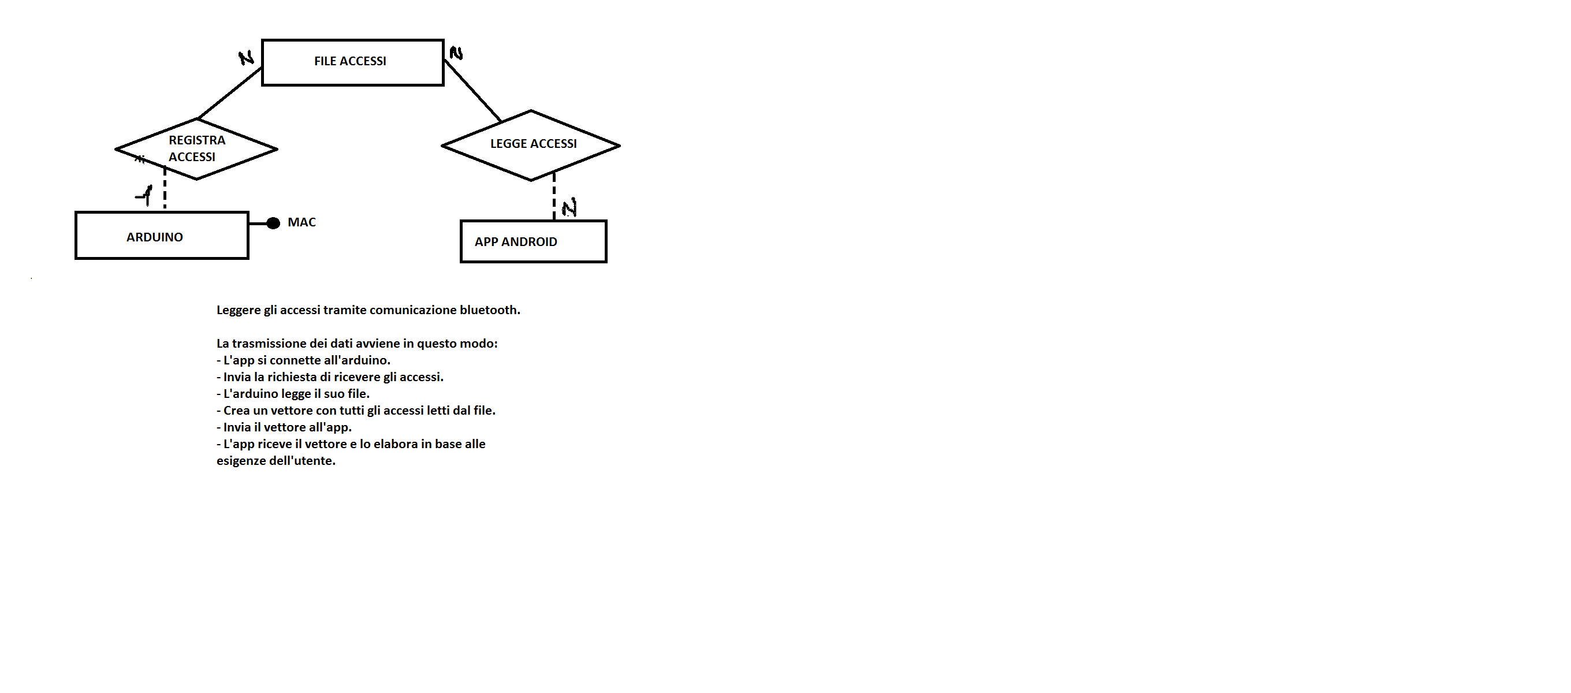
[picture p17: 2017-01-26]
Materiale/DiagramaERAccessi.png

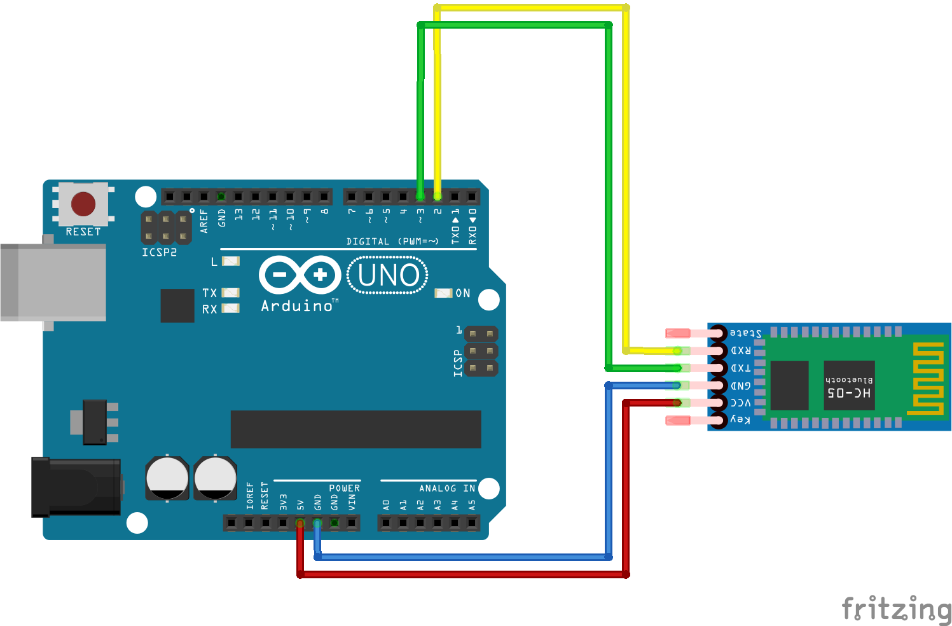
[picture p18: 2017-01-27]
Materiale/Schemi/HC-06.png

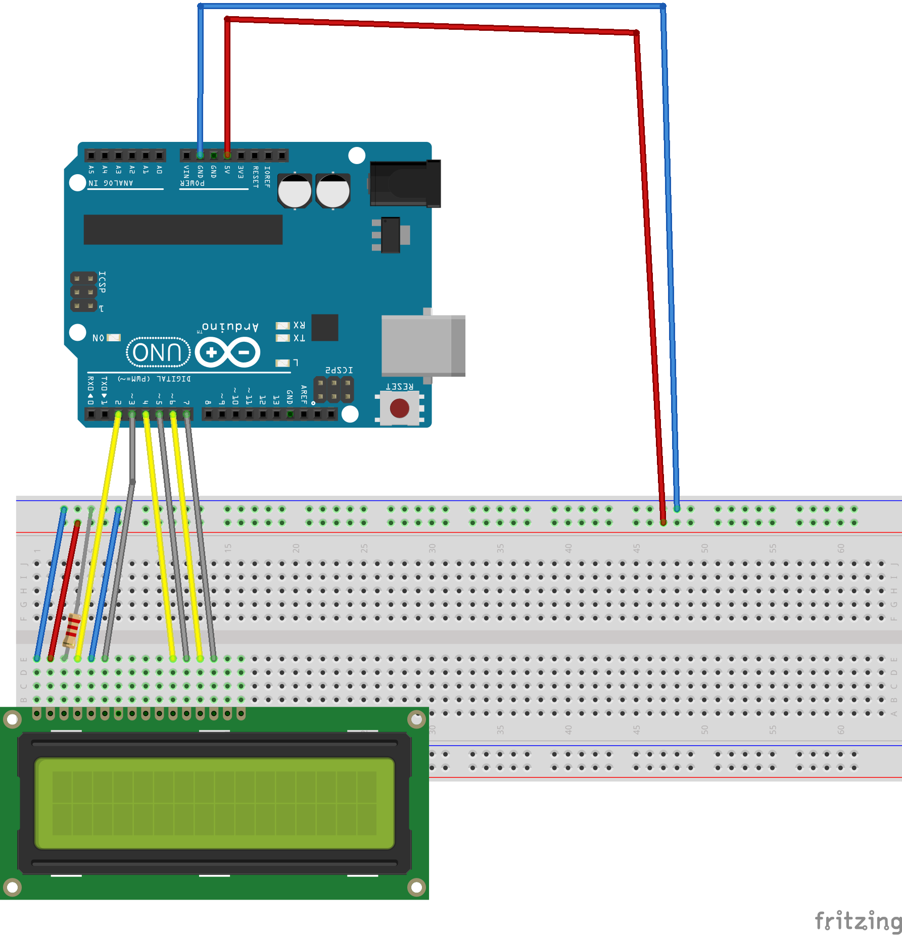
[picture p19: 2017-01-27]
Materiale/Schemi/Schermo.png

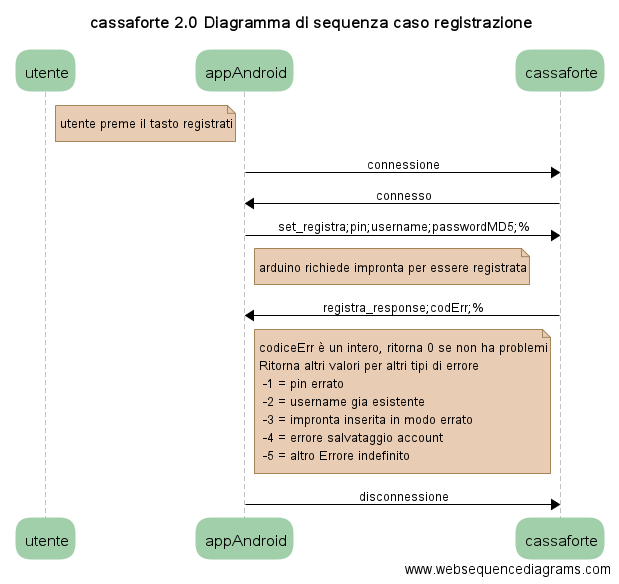
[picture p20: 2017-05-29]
Materiale/Protocolli/Diagrammi Sequenza/Immagini/registrazione.png

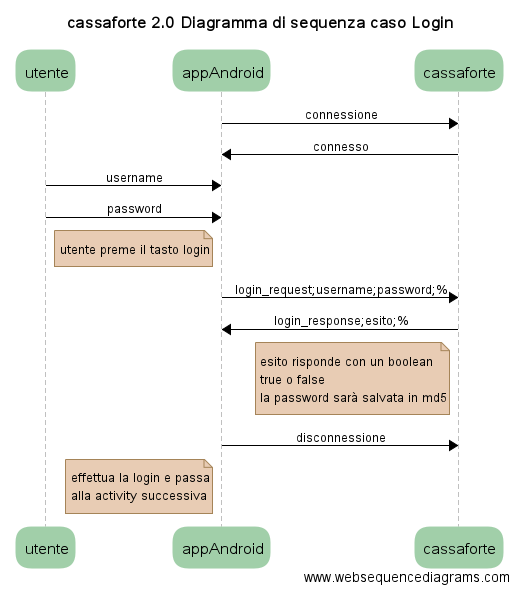
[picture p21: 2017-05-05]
Materiale/Protocolli/Diagrammi Sequenza/Immagini/login.png

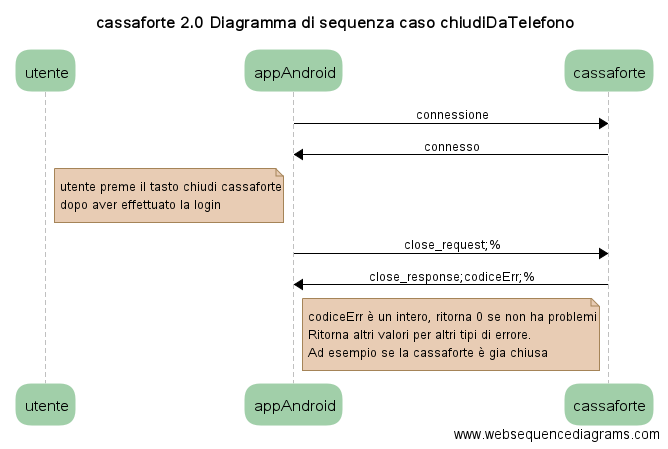
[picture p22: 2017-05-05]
Materiale/Protocolli/Diagrammi Sequenza/Immagini/chiudiCassaforteDaTelefono.png

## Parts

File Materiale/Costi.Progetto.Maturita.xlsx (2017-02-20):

MATERIALE | LINK | COSTO | LINK UTILI
Arduino | /// | €0.00
Cassa in legno | /// | €0.00
Tastierino numerico | Ebay (http://www.ebay.it/itm/111760916315?_trksid=p2060353.m2749.l2649&ssPageName=STRK%3AMEBIDX%3AIT) | €0.00
Schermo lcd | /// | €0.00
Motori chiusura e apertura | /// | €0.00
Shield comunicazione | Amazon (https://www.amazon.it/gp/product/B01J5CDXY8/ref=oh_aui_detailpage_o01_s00?ie=UTF8&psc=1) | €7.29 | Comunicazione (http://www.instructables.com/id/Connect-Arduino-Uno-to-Android-via-Bluetooth/)
Shield espansione memoria | Ebay (http://www.ebay.it/itm/111773200314?_trksid=p2060353.m2749.l2649&ssPageName=STRK%3AMEBIDX%3AIT) | €4.99
Sensore impronte digitali | Amazon (https://www.amazon.it/KOOKYE-impronte-serrature-tutto-unoper/dp/B019TPP1UK) | €35.50
Fotocamera | Mini in the box (http://www.miniinthebox.com/it/modulo-fotocamera-ov7670-300kp-vga-per-arduino-opere-con-ufficiali-arduino-boards_p1141472.html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) | €15.60
Clock | Amazon (https://www.amazon.it/gp/product/B01H5NAFUY/ref=oh_aui_detailpage_o00_s00?ie=UTF8&psc=1) | €7.99
Totale spese |  | €71.37
Spese attuali: | 20.27 | €20.27
Budget totale |  | €80.00

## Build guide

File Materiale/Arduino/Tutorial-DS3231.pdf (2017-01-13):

Tutorial DS 3231

TUTORIAL PER UN CORRETTO USO DEL MODULO REAL TIME CLOCK DS 3231

L' DS3231 è un modulo orologio in tempo reale (R.T.C.) a basso costo, con interfaccia di comunicazione I2C estremamente preciso con "a bordo" un oscillatore integrato compensato in temperatura a cristallo di quarzo (TCXO). Il dispositivo incorpora anche una batteria al Litio (sostituibile), che mantiene aggiornato l'orologio anche in assenza della alimentazione principale (5V). L'oscillatore integrato migliora l'accuratezza a lungo termine del dispositivo e riduce il numero di componenti esterni. Il DS3231 è disponibile in gamme di temperature commerciali e industriali, l'RTC mantiene secondi, minuti, ore, giorno, data, mese e anno. Per i mesi con meno di 31 giorni, la data di fine viene regolata automaticamente, comprese le correzioni per l'anno bisestile. L'orologio funziona in entrambi i formati: 24 ore oppure / AM / PM per l'indicazione del formato a 12 ore; fornisce due sveglie configurabili, indirizzo e dati sono trasferiti in serie attraverso un bus bidirezionale I2C. Il dispositivo integra un sensore di temperatura digitale (on-chip), interoperabile attraverso l'interfaccia I2C, la precisione del sensore di temperatura è ± 3°C; il circuito di controllo dell'alimentazione può rilevare automaticamente e gestire l'alimentazione principale e di standby. Se si verifica una interruzione dell’alimentazione principale, il dispositivo può continuare a fornire tempi precisi e temperature, detta interruzione non influenzano le prestazioni del dispositivo.

Parametri dell'unità:

- Dimensioni: 38mm (lunghezza) * 22mm (larghezza) * 14mm (altezza)
- Peso: 8 gr
- Tensione di esercizio: 3,3-5 V ±0,5 V
- Clock chip: DS3231 circuito integrato dell'orologio di alta precisione
- Precisione Orologio: 0-40 ℃ gamma, il 2 ppm accuratezza, l'errore è stato di circa 1 minuto
- Sveglie programmabili n° 2
- Uscita onda quadra programmabile
- Tempo reale del generatore di clock secondi, minuti, ore, giorno, data, mese e anno valido fino al 2100 bisestile compensazione anno
- Sensore di temperatura del circuito integrato è dotato di una precisione di ± 3 °C
- Chip di memoria: AT24C32 (32Kb)
- Interfaccia bus I2C ( velocità di trasmissione massima di 400KHz con tensione di lavora pari a 5V)
- Batteria al litio CR 2032 (o LIR 2032) per assicurare che il sistema dopo un'interruzione di corrente continui a tenere aggiornato tempo e data.
- Precisione: ± 1 sec/mese ± 63 secondi/anno

Pin da utilizzare
SCL → A5 (for Arduino old version)
SDA → A4 (for Arduino old version)
VCC → 5V
GND → GND

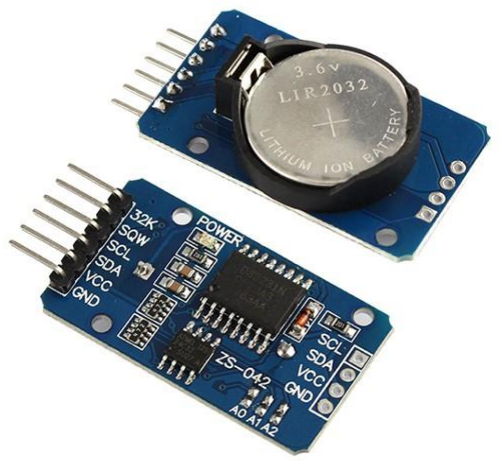
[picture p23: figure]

Una volta collegati correttamente tutti i pin possiamo scaricare la libreria DS 3231 di Eiric Ayars sul
nostro IDE Arduino dal seguente link: http://m5.img.dxcdn.com/CDDriver/CD/sku.222910.rar e caricare il
seguente codice di esempio direttamente dalla sezione esempi dell'IDE Arduino .

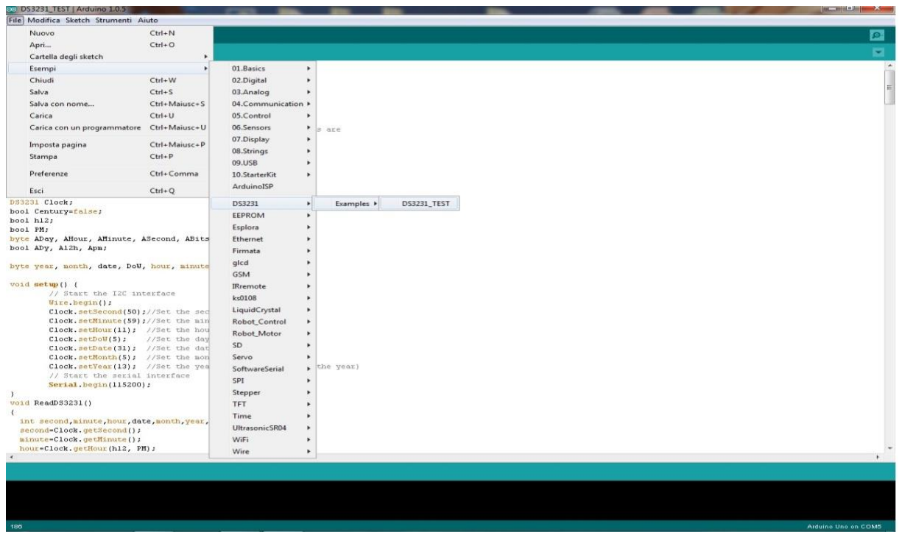
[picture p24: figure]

Leggeremo i dati direttamente sul serial monitor. Ovviamente dovremo impostare manualmente data e ora agendo sul codice. Purtroppo il modulo non contempla l'ora legale quindi, dovremo aggiornarla quando c'è il cambio (a marzo e a ottobre). Ecco il codice di Eric Ayars:

/*
DS3231_test.pde
Eric Ayars
4/11

Test/demo of read routines for a DS3231 RTC.

Turn on the serial monitor after loading this to check if things are working as they should.

*/

#include <DS3231.h>

#include <Wire.h>

DS3231 Clock;
bool Century=false;
bool h12;
bool PM;
byte ADay, AHour, AMinute, ASecond, ABits;
bool ADy, A12h, Apm;

byte year, month, date, DoW, hour, minute, second;

void setup() {
// Start the I2C interface Wire.begin();
Clock.setSecond(50);//Set the second Clock.setMinute(59);//Set the minute Clock.setHour(11); //Set the hour Clock.setDoW(5); //Set the day of the week Clock.setDate(31); //Set the date of the month Clock.setMonth(5); //Set the month of the year Clock.setYear(16); //Set the year (Last two digits of the year) // Start the serial interface
Serial.begin(115200);
}
void ReadDS3231()
{
int second,minute,hour,date,month,year,temperature; second=Clock.getSecond();
minute=Clock.getMinute();
hour=Clock.getHour(h12, PM); date=Clock.getDate();
month=Clock.getMonth(Century); year=Clock.getYear();

temperature=Clock.getTemperature();

Serial.print("20");
Serial.print(year,DEC);
Serial.print('-');
Serial.print(month,DEC);
Serial.print('-');
Serial.print(date,DEC);
Serial.print(' ');
Serial.print(hour,DEC);
Serial.print(':');
Serial.print(minute,DEC);
Serial.print(':');
Serial.print(second,DEC);
Serial.print('\n');
Serial.print("Temperature="); Serial.print(temperature); Serial.print('\n');
}
void loop() {ReadDS3231();delay(1000);
// send what's going on to the serial monitor.
// Start with the year
/* | Serial.print("2");
if (Century) { | // Won't need this for 89 years.
Serial.print("1");
} else {
Serial.print("0");
}
Serial.print(Clock.getYear(), DEC); Serial.print('-');

// then the month
Serial.print(Clock.getMonth(Century), DEC); Serial.print('-');
// then the date
Serial.print(Clock.getDate(), DEC); Serial.print(' ');*/
// and the day of the week /*Serial.print(Clock.getDoW(), DEC); Serial.print(' ');*/
// Finally the hour, minute, and second /*Serial.print(Clock.getHour(h12, PM), DEC); Serial.print(':');
Serial.print(Clock.getMinute(), DEC); Serial.print(':');
Serial.print(Clock.getSecond(), DEC); // Add AM/PM indicator
if (h12) {
if (PM) {
Serial.print(" PM ");
} else {
Serial.print(" AM ");
}
} else {
Serial.print(" 24h ");
}
// Display the temperature Serial.print("T=");
Serial.print(Clock.getTemperature(), 2);
// Tell whether the time is (likely to be) valid if (Clock.oscillatorCheck()) {
Serial.print(" O+");
} else {
Serial.print(" O-");
}*/
// Indicate whether an alarm went off /*if (Clock.checkIfAlarm(1)) { Serial.print(" A1!");
}
if (Clock.checkIfAlarm(2)) { Serial.print(" A2!");
}*/
// New line on display
//Serial.print('\n');
// delay(1000);
// Display Alarm 1 information
/* | Serial.print("Alarm 1: ");
| Clock.getA1Time(ADay, AHour, AMinute, ASecond, ABits, ADy, A12h, Apm);
| Serial.print(ADay, DEC);
| if (ADy) {
| Serial.print(" DoW");
| } else {
| Serial.print(" Date");
| }

Serial.print(' ');
Serial.print(AHour, DEC);
Serial.print(' ');
Serial.print(AMinute, DEC); Serial.print(' ');
Serial.print(ASecond, DEC); Serial.print(' ');
if (A12h) {
if (Apm) {
Serial.print('pm ');
} else {
Serial.print('am ');
}
}
if (Clock.checkAlarmEnabled(1)) { Serial.print("enabled");
}
Serial.print('\n');
// Display Alarm 2 information
Serial.print("Alarm 2: ");
Clock.getA2Time(ADay, AHour, AMinute, ABits, ADy, A12h, Apm); Serial.print(ADay, DEC);
if (ADy) {
Serial.print(" DoW");
} else {
Serial.print(" Date");
}
Serial.print(' ');
Serial.print(AHour, DEC);
Serial.print(' ');
Serial.print(AMinute, DEC); Serial.print(' ');
if (A12h) {
if (Apm) {
Serial.print('pm');
} else {
Serial.print('am');
}
}
if (Clock.checkAlarmEnabled(2)) { Serial.print("enabled");
}*/
/* display alarm bits
Serial.print('\n');
Serial.print('Alarm bits: '); Serial.print(ABits, DEC);
*/
/*
Serial.print('\n');
Serial.print('\n');
delay(1000);

// Display the time once more as a test of the getTime() function

Clock.getTime(year, month, date, DoW, hour, minute, second);

Serial.print(year, DEC);
Serial.print("/");
Serial.print(month, DEC);
Serial.print("/");
Serial.print(date, DEC);
Serial.print("day of the week :"); Serial.println(DoW, DEC);
Serial.print(hour, DEC);
Serial.print(":");
Serial.print(minute, DEC); Serial.print(":");
Serial.println(second, DEC);*/ }

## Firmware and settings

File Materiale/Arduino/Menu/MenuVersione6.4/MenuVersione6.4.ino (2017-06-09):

#include <Keypad.h>
#include <LiquidCrystal.h>  
#include <DS3232RTC.h>   
#include <TimeLib.h>         
#include <Wire.h>  
#include <SPI.h>
#include <SD.h>
#include <Adafruit_Fingerprint.h>

//test
String pswTest="1998";

//estensione memoria SD
File myFile;
int id = 1;
String userDaReg="";
String passDaReg="";


//impronte digitali
//collegamenti rosso->5v | nero->gnd | verde->d2 | bianco-d3
int ultimoIdRilevato=-1;
int getFingerprintIDez();
Adafruit_Fingerprint finger = Adafruit_Fingerprint(&Serial2);
boolean esitoLettura=false;
int idLettura=-1;
String message="";
String logIn="login_request;BeppeL;c7cc6a1fd6d6b5f4817025cb532b52fa;%";
boolean fineMSGPERC=false;


//lcd, configurazione e collegamenti
//VSS->gnd | VDD->vcc | V0->potenziometro | RS->7 | RW->gnd | E->6 | D4->5 | D5->4 | D6->3 | D7->2 | A->vcc330Hom | K->gnd
LiquidCrystal lcd(7, 6, 5, 4, 3, 2);
//LiquidCrystal lcd(2, 3, 4, 5, 6, 7);
int stato=0;
String lettura="";
boolean chiuso=true;

//pin motorini serratura
int m0=32, m1=33, m2=34, m3=35;//50,51,52,53
long secondiStop=0;
int minutiCambioOra=0;
int tempoApertChius=5;


const byte ROWS = 4; //four rows
const byte COLS = 3; //three columns
char keys[ROWS][COLS] = {
  {'1','2','3'},
  {'4','5','6'},
  {'7','8','9'},
  {'*','0','#'}
};
byte rowPins[ROWS] = {22, 23, 24, 25}; //connect to the row pinouts of the keypad 2-7-6-4 || 4-5-6-7
byte colPins[COLS] = {26, 27, 28}; //connect to the column pinouts of the keypad 3-1-5 || 1-2-3

Keypad keypad = Keypad( makeKeymap(keys), rowPins, colPins, ROWS, COLS );

void setup(){
  Serial.begin(9600);
  Serial1.begin (9600);//clock
  Serial3.begin(9600);
   lcd.begin(16, 2);  
   lcd.setCursor(0, 0); 
   lcd.print("Ins. codice...");
   lcd.setCursor(0, 1); 
   lcd.print("Ins:");
   lcd.setCursor(4, 1);    

   //pin motorino setup
   pinMode(m0, OUTPUT);
  pinMode(m1, OUTPUT);
  pinMode(m2, OUTPUT);
  pinMode(m3, OUTPUT);

//imposto le uscite a livello logico basso
  digitalWrite(m0, LOW);
  digitalWrite(m1, LOW);
  digitalWrite(m2, LOW);
  digitalWrite(m3, LOW);

//rtc
    setSyncProvider(RTC.get);   // the function to get the time from the RTC
    if(timeStatus() != timeSet) 
        Serial.println("Unable to sync with the RTC");
    else
        Serial.println("RTC has set the system time"); 

//sensore impronte digitali
  finger.begin(57600);
  
  if (finger.verifyPassword()) {
    Serial.println("Found fingerprint sensor!");
  } else {
    Serial.println("Did not find fingerprint sensor :(");
    //while (1);
  }
//memoria SD

Serial.print("Inizializzazione Card: ");
  if (!SD.begin(53)) //il Pin 53 è collegato a CS
  {
    Serial.println("FALLITA!");
  }
  else{
    Serial.println("ESEGUITO!");
    }
  


        stampaData(); 
        minutiCambioOra=minute();
}


//--metodi
void printDigits(int digits)
{
    // utility function for digital clock display: prints preceding colon and leading 0
    Serial.print(':');
    if(digits < 10)
        Serial.print('0');
    Serial.print(digits);
}

void digitalClockDisplay(void)
{
    // digital clock display of the time
    Serial.print(hour());
    printDigits(minute());
    printDigits(second());
    Serial.print(' ');
    Serial.print(day());
    Serial.print(' ');
    Serial.print(month());
    Serial.print(' ');
    Serial.print(year()); 
    Serial.println(); 
}

  //gestisce la lettura del tastierino elaborandola
 void gestisciInsert(String lettura){

  //leggo il primo carattere per sapere se è una password di accesso o un comando
  String tp=lettura.substring(0,1);  
  Serial.print("Lettura prima di entrare nel controllo: ");
  Serial.println(lettura);
  if(tp=="*"){//se il primo carattere è un *, allora è un comando
   /* Serial.println("----------dentro if tp");
    Serial.print("----------LEttura lettura: ");
     Serial.println(lettura);
    Serial.print("----------Lettura tp: ");
    Serial.println(tp);*/
    if(lettura=="*1"){ stato=1; Serial.println("----------dentro if tp -----------stato 1");}
    else if(lettura=="*2"){ stato=2; Serial.println("----------dentro if tp -----------stato 2");}
    else if(lettura=="*3"){ stato=3; Serial.println("----------dentro if tp -----------stato 3");}
    else if(lettura=="*4"){ stato=4; Serial.println("----------dentro if tp -----------stato 4");}
    else if(lettura=="*5"){ stato=5; Serial.println("----------dentro if tp -----------stato 5");}
    else if(lettura=="*6"){ stato=6; Serial.println("----------dentro if tp -----------stato 6");}
    else if(lettura=="*7"){ stato=7; Serial.println("----------dentro if tp -----------stato 7");}
    else if(lettura=="*1234567890"){ stato=1234567890; Serial.println("----------dentro if tp -----------stato 1234567890");}
    else { stato=-1; Serial.println("----------dentro if tp -----------stato -1 ERRORE");}
  }//fine if controllo
  else{//se è una password controllo su database
    Serial.print("Lettura prima di entrare nel controllo DELLA PASSWORD : ");
  Serial.println(lettura);
    Serial.println("controllo psw");
    if(pswTest==lettura){
        stato=2;
        Serial.println("--******--dentro if controllo PASSWORD --******-- stato 2");
      }    
     else if(lettura==""){
      Serial.println("Chiudo Cassaforte");
      //chiudi();
      stato=4;
      lettura="";
      pulisciLCD();
      }
      else{
        stato=-1;
        }

    lettura="";
   
    pulisciLCD();
   // valore=1;
  }
  
  //return valore;
 }

 
void pulisciLCD(){
  lcd.setCursor(4, 1); 
    lcd.print("            ");
    delay(100);
     lcd.setCursor(4, 1);   
}

  //metodi motorino
void  fase1(){
   //FASE 1
    //Alimento solo la prima bobina
    digitalWrite(m0, HIGH);
    digitalWrite(m1, LOW);
    digitalWrite(m2, LOW);
    digitalWrite(m3, LOW);
    delay(10);
  }
  
 void fase2(){
  //FASE 2
    //Alimento solo la seconda bobina
    digitalWrite(m0, LOW);
    digitalWrite(m1, HIGH);
    digitalWrite(m2, LOW);
    digitalWrite(m3, LOW);
    delay(10);
  }
  
void  fase3(){
  //FASE 3
    //Alimento solo la terza bobina
    digitalWrite(m0, LOW);
    digitalWrite(m1, LOW);
    digitalWrite(m2, HIGH);
    digitalWrite(m3, LOW);
    delay(10);
  }
  
void  fase4(){
  //fase 4
    //Alimento solo la quarta bobina
    digitalWrite(m0, LOW);
    digitalWrite(m1, LOW);
    digitalWrite(m2, LOW);
    digitalWrite(m3, HIGH);
    delay(10);
  }


 void avanti(){
    fase1();
    fase2();
    fase3();
    fase4();
  }

void  indietro(){
    fase4();
    fase3();
    fase2();
    fase1();
  }

 //metodo per portare tutte le bobine del motorino a LOW 
void tuttoSpento(){
      digitalWrite(m0, LOW);
    digitalWrite(m1, LOW);
    digitalWrite(m2, LOW);
    digitalWrite(m3, LOW);
  }
//problema riscontrato: calcolo basato sui secondi da problemi a cavallo tra un minuto e un altro
void apri(){
 if(chiuso){ //se chiuso è uguale a true, quindi se è chiuso apri
  lcd.setCursor(4,1);
  lcd.print("Apertura...");
  secondiStop=now()+tempoApertChius;
 
    while(now()<secondiStop){
    indietro();
    }
    tuttoSpento();
    secondiStop=0;
    chiuso=false;
 }
}
void chiudi(){
if(!chiuso){// se chiuso è a false quindi è aperto
   lcd.setCursor(4,1);
  lcd.print("Chiusura...");
secondiStop=now()+tempoApertChius;
    
    while(now()<secondiStop){
    avanti();
    }
    tuttoSpento();
     secondiStop=0;
     chiuso=true;
     esitoLettura=false;
  }
}

void stampaData(){
 lcd.setCursor(0, 0); 
   lcd.print(day()); 
   lcd.print("/");
    lcd.print(month()); 
   lcd.print("/");
    lcd.print(year()); 
   lcd.print(" ");
    lcd.print(hour()); 
   lcd.print(":");
    if(minute() < 10)
        lcd.print('0');
    lcd.print(minute());

    lcd.setCursor(4,1);
 }

 //metodi lettore impronte digitali

 void letturaImpronte(){
    secondiStop=now()+10;
    
     //codice per la visualizzazione su lcd
   lcd.setCursor(0, 1); 
   lcd.print("ins. Impronta...");
   lcd.setCursor(4, 1); 
   
    do{
    esitoLettura = leggiImpronta();
    }while(esitoLettura==false && now()<secondiStop);
      
   //codice per la visualizzazione su lcd
  lcd.setCursor(0, 1); 
   lcd.print("Ins:");
   lcd.setCursor(4, 1);
   pulisciLCD();
  }
void letturaImpronteApertura(){
  
  Serial.print("Stato dentro stato 2: "); Serial.println(stato);                            
   Serial.println("caso lettura impronte digitali");
    secondiStop=now()+10;
    
     //codice per la visualizzazione su lcd
   lcd.setCursor(0, 1); 
   lcd.print("ins. Impronta...");
   lcd.setCursor(4, 1); 
   
    do{
    esitoLettura = leggiImpronta();
    }while(esitoLettura==false && now()<secondiStop);
      Serial.println("Finita lettura");
   //codice per la visualizzazione su lcd
  lcd.setCursor(0, 1); 
   lcd.print("Ins:");
   lcd.setCursor(4, 1);
   pulisciLCD();
   Serial.println("Inizio esito lettura");
    if(esitoLettura){
      Serial.println("Dentro esito lettura e salvataggio");
      setlog(ultimoIdRilevato,day(), month(), year(), hour(), minute(), second());
      Serial.println("finito salvataggio");
      Serial.print("Impronta appartenente a ID: ");
   Serial.println(ultimoIdRilevato);
      ultimoIdRilevato=-1;
      apri();
    }
    else
    {
      Serial3.write("open_response;-4;%");//impronta errata
      Serial.print("Impronta appartenente a ID: ");
   Serial.println(ultimoIdRilevato);
      Serial.println("Errore Impronta");
      }
   
   pulisciLCD();
   lettura="";
   message="";
   
    stato=0;
    
  }
 
uint8_t getFingerprintID() {
  uint8_t p = finger.getImage();
  switch (p) {
    case FINGERPRINT_OK:
      Serial.println("Image taken");
      break;
    case FINGERPRINT_NOFINGER:
      Serial.println("No finger detected");
      return p;
    case FINGERPRINT_PACKETRECIEVEERR:
      Serial.println("Communication error");
      return p;
    case FINGERPRINT_IMAGEFAIL:
      Serial.println("Imaging error");
      return p;
    default:
      Serial.println("Unknown error");
      return p;
  }

  // OK success!

  p = finger.image2Tz();
  switch (p) {
    case FINGERPRINT_OK:
      Serial.println("Image converted");
      break;
    case FINGERPRINT_IMAGEMESS:
      Serial.println("Image too messy");
      return p;
    case FINGERPRINT_PACKETRECIEVEERR:
      Serial.println("Communication error");
      return p;
    case FINGERPRINT_FEATUREFAIL:
      Serial.println("Could not find fingerprint features");
      return p;
    case FINGERPRINT_INVALIDIMAGE:
      Serial.println("Could not find fingerprint features");
      return p;
    default:
      Serial.println("Unknown error");
      return p;
  }
  
  // OK converted!
  p = finger.fingerFastSearch();
  if (p == FINGERPRINT_OK) {
    Serial.println("Found a print match!");
  } else if (p == FINGERPRINT_PACKETRECIEVEERR) {
    Serial.println("Communication error");
    return p;
  } else if (p == FINGERPRINT_NOTFOUND) {
    Serial.println("Did not find a match");
    return p;
  } else {
    Serial.println("Unknown error");
    return p;
  }   
  
  // found a match!
  ultimoIdRilevato=finger.fingerID;
  Serial.print("Found ID #"); Serial.print(finger.fingerID); 
  Serial.print(" with confidence of "); Serial.println(finger.confidence); 
}

int getFingerprintIDez() {
  uint8_t p = finger.getImage();
  if (p != FINGERPRINT_OK)  return -1;

  p = finger.image2Tz();
  if (p != FINGERPRINT_OK)  return -1;

  p = finger.fingerFastSearch();
  if (p != FINGERPRINT_OK)  return -1;
  
  // found a match!
  ultimoIdRilevato=finger.fingerID;
  Serial.print("Found ID #"); Serial.print(finger.fingerID); 
  Serial.print(" with confidence of "); Serial.println(finger.confidence);
   esitoLettura=true;
   idLettura=finger.fingerID;
}
boolean leggiImpronta(){
      //metodo per la lettura del sensore di impronte digitali
   getFingerprintIDez();
  delay(50);

  return esitoLettura;
  }

void msgBT(){
   while(Serial3.available() > 0) {//attende fino a che seriale non riceve qualcosa
 //gestiscoIlmessaggio
    char lettoCh=Serial3.read();
    message+=lettoCh;
    if(lettoCh=='%'){
      fineMSGPERC=true;
      }
   }
   if(message!=""){
    Serial.print("messaggio: ");
  Serial.println(message);
    }
  
if(fineMSGPERC){
  //faccio lo substring della prima parte per capire che tipo di messaggio sto ricevendo
   int primoPuntoVirgola = message.indexOf(';');
   String tipoMSG = message.substring(0, primoPuntoVirgola+1);
 Serial.print("messaggio tipo: ");
  Serial.println(tipoMSG);

   if(tipoMSG=="login_request;"){
     Serial.println("Dentro loginrequest");
     int trovPerc = message.indexOf('%');
    message=message.substring(primoPuntoVirgola+1, trovPerc+1);
     Serial.print("messaggio per user: ");
  Serial.println(message);
    int secondoPuntoVirgola = message.indexOf(';');
    String username=message.substring(0, secondoPuntoVirgola);
    trovPerc = message.indexOf('%');
    message=message.substring(secondoPuntoVirgola+1, trovPerc+1);
    int terzoPuntoVirgola = message.indexOf(';');
    Serial.print("messaggio per pass: ");
  Serial.println(message);
    String password=message.substring(0, terzoPuntoVirgola);
    Serial.print("Username: ");
    Serial.println(username);
     Serial.print("Password: ");
    Serial.println(password);

  //!!!^^^!!! DA IMPLEMENTARE
String messRitorno=findCredenzialiUser(username, password);
      String msgResponse="login_response;"+messRitorno+";%";
      Serial.println("Messaggio risposta: "+msgResponse);
      
      //Serial3.write(msgResponse);
      
    /*if(username=="BeppeL" && password=="c7cc6a1fd6d6b5f4817025cb532b52fa"){
      Serial3.write("TTRUEE");
      }
      else{
        Serial3.write("FFALSE");
        }*/

    if(messRitorno=="0"){
      Serial.write("TTRUEE");
      //Serial3.write("TTRUEE");
      }
      else{
        Serial.write("FFALSE");
        //Serial3.write("FFALSE");
        }    
    fineMSGPERC=false;
    message="";
    //stato=2;
  }

  else if(tipoMSG=="get_datiLog_request;"){
    //prendo i valori del messaggio
    Serial.println("Dentro getDatiLog");
     int trovPerc = message.indexOf('%');
    message=message.substring(primoPuntoVirgola+1, trovPerc+1);
     Serial.print("messaggio per user: ");
  Serial.println(message);
    int secondoPuntoVirgola = message.indexOf(';');
    String username=message.substring(0, secondoPuntoVirgola);
    trovPerc = message.indexOf('%');
    message=message.substring(secondoPuntoVirgola+1, trovPerc+1);
    int terzoPuntoVirgola = message.indexOf(';');
    Serial.print("messaggio per pass: ");
  Serial.println(message);
    String data=message.substring(0, terzoPuntoVirgola);
    Serial.print("Username: ");
    Serial.println(username);
     Serial.print("data: ");
    Serial.println(data);
    
    //richiamo il metodo per trovare nella memoria i dati di log, prima però devo verificare le credenziali dell'username
    //quindi gli passerò username e la data dei log che devo visualizzare
                //!!!^^^!!!! METODO DA IMPLEMENTARE
    /*String messRitorno=getDatiLog(username, data);
        if(messRitorno.length()<3){
          String msgResponse="get_datiLog_response;"+messRitorno+";%";
          Serial3.write(msgResponse);
          }
         else{
          String msgResponse="get_datiLog_response;0;%";
          }
    Serial3.write(messRitorno);
    Serial3.write("get_datiLog_end;%");*/
    fineMSGPERC=false;
    message="";
    
    }
   else if(tipoMSG=="close_request;"){
    Serial.println("Dentro closerequest");
    stato=4;
    if(chiuso){
      Serial3.write("close_response;-1;%");
      }
     else if(!chiuso){
      Serial3.write("close_response;0;%");
      }
    
     fineMSGPERC=false;
    message="";
    }
   else if(tipoMSG=="open_request;"){
       Serial.println("Dentro getDatiLog");
     int trovPerc = message.indexOf('%');
    message=message.substring(primoPuntoVirgola+1, trovPerc+1);
     Serial.print("messaggio per user: ");
  Serial.println(message);
    int secondoPuntoVirgola = message.indexOf(';');
    String username=message.substring(0, secondoPuntoVirgola);
    trovPerc = message.indexOf('%');
    message=message.substring(secondoPuntoVirgola+1, trovPerc+1);
    int terzoPuntoVirgola = message.indexOf(';');
    Serial.print("messaggio per pass: ");
  Serial.println(message);
    String pin=message.substring(0, terzoPuntoVirgola);
    Serial.print("Username: ");
    Serial.println(username);
     Serial.print("Pin: ");
    Serial.println(pin);
    if(chiuso){
       if(username=="BeppeL"){
            if(pin==pswTest){
              Serial3.write("open_response;0;%");
              stato=2;
            }
              else{
              Serial3.write("open_response;-2;%");//pin errato
            }
          }        
        else{
          Serial3.write("open_response;-1;%");//username errato
          }
       }
        else{
          Serial3.write("open_response;-3;%");//cassaforte gia aperta
       }
   
     fineMSGPERC=false;
        message="";
    }
     else if(tipoMSG=="set_registra;"){
           Serial.println("Dentro registra");
         int trovPerc = message.indexOf('%');
        message=message.substring(primoPuntoVirgola+1, trovPerc+1);
        Serial.print("messaggio per user: ");
        Serial.println(message);
        int secondoPuntoVirgola = message.indexOf(';');
        String pin=message.substring(0, secondoPuntoVirgola);
        trovPerc = message.indexOf('%');
        message=message.substring(secondoPuntoVirgola+1, trovPerc+1);
        int terzoPuntoVirgola = message.indexOf(';');
        Serial.print("messaggio per pass: ");
        Serial.println(message);
        String username=message.substring(0, terzoPuntoVirgola);
        message=message.substring(terzoPuntoVirgola+1, trovPerc+1);
         int quartoPuntoVirgola = message.indexOf(';');
        Serial.print("messaggio per pass: ");
        Serial.println(message);
        String password=message.substring(0, quartoPuntoVirgola);

        Serial.print("Password: ");
        Serial.println(password);
        Serial.print("Username: ");
        Serial.println(username);
         Serial.print("Pin: ");
        Serial.println(pin);

        userDaReg=username;
        passDaReg=password;

         Serial.print("user da reg: ");
        Serial.println(userDaReg);

         Serial.print("pass da reg: ");
        Serial.println(passDaReg);


      if(pin==pswTest){
       if(!verificaUtente(username)){
         stato=5;
        }
        else{
             Serial.println("username gia esistente");
            Serial3.write("registra_response;-2;%");//username gia esistente
          }
        }
      else{
         Serial.println("pin errato");//cj174js -- bc ***NC | 
          Serial3.write("registra_response;-1;%");//pin errato
       }
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
void loop(){
   char key; 


switch (stato){
  case 0:
  {
     //digitalClockDisplay();  
     if(minutiCambioOra!=minute()){
      stampaData();
      minutiCambioOra=minute();
      }
     key = keypad.getKey();
     msgBT();
          if (key != NO_KEY){
                  if(key=='#'){
                        Serial.print("Lettura: ");
                        Serial.println(lettura);
                        gestisciInsert(lettura);
                        //stato=gestisciInsert(lettura);
                        Serial.println("Cambiato stato");
                        Serial.println(stato);  
                       
                    }
              
              lcd.print("*");
              lettura+=key;
              
              //codice di controllo
              Serial.print("key: ");
              Serial.println(key);
              Serial.print("Stato: ");
              Serial.println(stato);    
    }break;

  case 1:
  {
    Serial.print("Stato dentro stato 1: ");
              Serial.println(stato);  
  digitalClockDisplay();  
  delay(1000);
  digitalClockDisplay();

    Serial.println("caso1");
    Serial.println("cambio lo stato a 0");
    delay(2000);
    pulisciLCD();
    lettura="";
    stato=0;
    }break;
  }

  case 2:
  {
    letturaImpronteApertura();
     lettura="";
   message="";
   
    stato=0;
    
    }break;

  case 3:
  {
    Serial.println("Caso 3| test apertura");
   apri();
     pulisciLCD();
   lettura="";
    stato=0;
    }break;

  case 4:
  {
     Serial.println("Caso 4| test chiusura");
    chiudi();
     pulisciLCD();
   lettura="";
    stato=0;
    }break;

  case 5:
  {
    //memorizzazione nuova impronta digitale
      secondiStop=now()+30;
    Serial.println("Ready to enroll a fingerprint! Please Type in the ID # you want to save this finger as...");
      //id = readnumber();
      id=findLastId();
      //id=getIDregistra();
      Serial.print("Enrolling ID #");
     // Serial.println(id);
      
      while (!getFingerprintEnroll() && now()<secondiStop);

           letturaImpronte();
          registraUserPass(ultimoIdRilevato, userDaReg, passDaReg);
          //...

    
    pulisciLCD();
   lettura="";
    stato=0;
    }break;

  case 6:
  {
    pulisciLCD();
   lettura="";
    stato=0;
    }break;

 case 7:
  {
    pulisciLCD();
    lettura_sd_utenti();
   lettura="";
    stato=0;
    }break;
case 1234567890:
  {
    Serial.println("Stampo tutte le variabili...");
    delay(300);
    Serial.print("pswTest: "); Serial.println(pswTest);
    Serial.print("EsitoLettura: "); Serial.println(esitoLettura);
    Serial.print("idLettura: "); Serial.println(idLettura);
    Serial.print("stato: "); Serial.println(stato);
    Serial.print("lettura: "); Serial.println(lettura);
    Serial.print("chiuso: "); Serial.println(chiuso);
    Serial.print("tempo Apertura e chiusura: "); Serial.println(tempoApertChius);
    
    pulisciLCD();
   lettura="";
    stato=0;
    }break;
  case -1:
  {
    Serial.println("errore, codice menue inesistente");
    pulisciLCD();
    lcd.print("Err. menu");
    delay(1000);
    pulisciLCD();
   lettura="";
    stato=0;
    }break;

  default:
  {
    Serial.println("errore");
    }break;
  
  
  }
 
}

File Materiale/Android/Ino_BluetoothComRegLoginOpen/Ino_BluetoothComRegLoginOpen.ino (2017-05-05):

#include <SoftwareSerial.h>

//NOTA IMPORTANTE, il piedino rx e tx del modulo HC-06 vano collegati rispettivamente al tx e rx di arduino(rx va con tx e tx con rc, si invertono)
const int rxpin = 2;  //Andiamo ad assegnare al pin 2 l’indirizzo di ricezione dati (e lo colleghiamo al pin TXD del modulo)
const int txpin = 3;  //Assegnamo invece al pin 3 l’indirizzo di trasmissione dati (collegandolo al pin RXD del nostro componente
SoftwareSerial bluetooth(rxpin, txpin);  //Assegnamo ad un nome (bluetooth) i suoi pin di ricezione e trasmissione, per facilitarci la scrittura del codice
String message;
String logIn="login_request;BeppeL;c7cc6a1fd6d6b5f4817025cb532b52fa";
String request="registration_request;BeppeL;c7cc6a1fd6d6b5f4817025cb532b52fa"; /*;81dc9bdb52d04dc20036dbd8313ed055*/
String requestOpen="open_request;BeppeL;c7cc6a1fd6d6b5f4817025cb532b52fa"; 
String requestClose="close_request;BeppeL;c7cc6a1fd6d6b5f4817025cb532b52fa"; 

String requestCheckPin="open_request;81dc9bdb52d04dc20036dbd8313ed055"; /*;81dc9bdb52d04dc20036dbd8313ed055*/
String newRegistration="";
void setup(){
   pinMode(13, OUTPUT);
    
    Serial.begin(9600);  //Inizializziamo l’interfaccia seriale al baud rate dell’AT-mode
    bluetooth.begin(9600);  //Inizializziamo l’interfaccia del modulo bluetooth sempre al baud rate riferito alla modalità AT
  }
  
  void loop(){
    while(bluetooth.available()){
        message+=char(bluetooth.read());
  }
  if(!bluetooth.available())
  {
    Serial.println(message);
    if(message==logIn){//se arrivano informazioni
      delay(200);
      bluetooth.write("TTRUEE");
      Serial.println("Inviato ");
      message=""; //pulisci il messaggio
    }
   
    if(message==request){//se arrivano informazioni
      delay(200);
      newRegistration=message;//registrato
      bluetooth.write("TTRUEE");//invio conferma
      Serial.println("Inviato ");
      message=""; //pulisci il messaggio
    }
    if(message==requestCheckPin){
      delay(200);
      bluetooth.write("TTRUEE");
      Serial.println("Inviato ");
      message=""; //pulisci il messaggio
    }
    if(message==requestClose){
      delay(200);
      Serial.println("Chiusura cassaforte");
      message=""; //pulisci il messaggio
    }
    if( message == requestOpen){
      delay(200);
      Serial.println("Apertura cassaforte");
      message=""; //pulisci il messaggio
    }
     if(message!=logIn && message!="" && message!=request){
      delay(200);
      bluetooth.write("FFALSE");
      Serial.println("Else Inviato ");
      message=""; //pulisci il messaggio
    }
    

  }
  delay(500); //attendi


  }

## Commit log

2016-11-23 Costi
    File con costi e link d' acquisto prodotti
    [Costi.Progetto.Maturita.xlsx]
2016-11-23 Costi Materiale
    File excel con costi materiali e link per l' acquisto
    [Costi.Progetto.Maturita.xlsx]
2016-11-23 Link Visualizzazione Database Android
    Serie di link in cui viene spiegata la visualizzazione dei database tramite le list view
2016-11-23 Update Librerie Arduino.txt
2017-01-11 Costi Materiale
    [Costi.Progetto.Maturita.xlsx]
2017-01-24 SplashScreen App Android
    Progetto di AndroidStudio in cui è stato sviluppato lo splash screen della futura applicazione.
2017-01-27 App1.0
    Questa versione permette di comunicare con l'arduino tramite bluetooth con i vari metodi delle classi implementate nell'activity "Connessione". (Funzionante)
2017-01-27 AppV2
    L'applicazione ora implementa anche la classe BluetoothComIno, la quale racchiude tutti i metodi per connettere l'app all'arduino. Non è ancora stata testata.
2017-02-03 lettura stringhe di codice
2017-02-03 motorino step to step
2017-03-01 Add files via upload
    Da risolvere il problema della ricezione da arduino.
2017-03-15 Libreria sensore impronte digitali
2017-03-15 SafeV2Accessi
    Versione contenente gli accessi modificati con il custom Adaptor
2017-03-24 impronte per arduino mega
2017-04-05 Versione da finire
    Problema riguardante il calcolo di secondi in apertura e chiusura
2017-04-06 Funzionante
    Il problema dela chiusura e apertura è stato risolto utilizzando il metodo now() al posto i second(),
    Sullo schermo LCD l'ora si aggiorna ogni minuto,
    Creato un metodo per stampare l'ora si schermo LCD,
    Problema per quanto riguarda l'alimentazione, attaccati Keypad, schermo LCD, modulo RTC e motorino Step-to-Step, la corrente durante l'utilizzo del motorino per apertura e chiusura non è sufficente per mantenere le scritte a video sullo schermo LCD, problema risolto alimentando il motorino Step-to-Step con una batteria da 9V.
    Sistemata la grafica stampata su schermo LCD.
    [MenuVersione6.ino]
2017-04-12 menu 6.1
    aggiunta programma per gestire sensore di impronte
2017-04-21 modifica di nomi di alcuni menu e aggiunta protocolli, riorganizzazione cartella arduino
2017-04-21 aggiunti protocolli per richiedere i dati di accesso e riorganizzati in cartelle
2017-04-24 SafeV4_CorrezioneBug_Registration
    Sono stati corretti alcuni bug, inoltre la comunicazione è stata implementata nuovamente con la classe BluetoothComIno.
    E' stato implementato il caso d'uso della registrazione, vedere il file all'interno della cartella del progetto "LivelloDiAvanzamento.txt" per ulteriori dettagli.
    Questo file rar contiene ancheil file di arduino che permette sia di loggarsi che di registrarsi.
2017-04-25 SafeV5_LogRegApreChiude
    In questa versione è stata anche implementata la possibilità di aprire e chiudere la cassaforte, consultare il file livelloDiAvanzamento.txt perulteriori dettagli.
2017-05-07 aggiornamento menu e correzione bug
    [MenuVersione6.2.ino, MenuVersione6.3.ino]
2017-05-12 aggiunto prova per il bluetooth(non testato)
2017-05-24 versione con gestione login di prova
2017-05-28 inversione movimento del motorino
    inversione movimento del motorino per apertura e chiusura, in seguito all'assemblaggio il motorino deve muoversi in direzione inversa
2017-05-30 Update Metodi e descizione metodi per la gestione della memoria.txt
2017-05-31 aggiunta possibilità di memorizzare nuove impronte
2017-06-01 QuasiFunzionante
    Funzionano i codici di errore, codice zero non ancora testato
2017-06-06 Bug ricezione login
    Aggiunta codice per ricezione stringhe dinamiche login.
    Aggiunta codice per la registrazione
2017-06-10 Fino a implementazione accessi falliti
    Correzione di alcuni bug e implementazione dell'activity accessi falliti.
    Funziona abbastanza bene.
    Vedere file livelloDiAvanzamento per informazioni più dettagliate.
2017-06-10 Bottoni per la gestione degli accessi
    Aggiunti bottoni nell'action bar che permettono di aggiornare li accessi e di pulire la schermata.
    Manca comunicazione e parametro di ricerca.
2017-06-10 Aggiunta della data come parametro di ricerca
    Modificato anche il nome della prima activity.
    Aggiunta condizione "if(connesso)" all'onresume e pause dell'activity splashscreen --> da testare
2017-06-11 Implementata la comunicazione
    Implementati i metodi per la comunicazione ma non sono ancora stati testati.
2017-06-12 bug sulla gestione file sistemati
    [MenuVersione6.5.ino]
2017-06-12 aggiornato
    manca le gestione corretta dell'invio dei gile di log,
    corertto errore con comando Serial3.write(string.c:str());
    [MenuVersione6.5.ino]
2017-06-12 Versione stabilizzata
    Corretti alcuni bug nelle varie activity, principalmente nell'activity di registrazione.
    Ora, almeno in locale, non crasha più.
2017-06-14 Stabilina
    Il crash quando viene richiesto di aggiornare gli accessi è dovuto al fatto che richiama il metodo per splittare i dati che non funziona bene perchè da arduino mi hanno cambiato il traccaito record.
2017-06-15 bug sistemati e aggiornato
    [MenuVersione6.6.ino]
2017-06-15 presentazione genereale
    manca la parte personale di ogni componente
2017-06-23 Presentazione generale
    Presentazione in ppt generale, uguale per tutto il gruppo. Questa è la base per inserire poi la propria parte.
2017-06-23 Programma Arduino Definitivo
